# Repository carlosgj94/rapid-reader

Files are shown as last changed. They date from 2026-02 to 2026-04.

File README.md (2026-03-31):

# MOTIF

Embedded Rust firmware for an ESP32-S3 board with a Sharp LS027 memory LCD.

This repository is in a docs-first rebuild state.

Today:

- `src/bin/main.rs` is a minimal bring-up baseline
- `crates/ls027b7dh01` contains the reusable display driver primitives
- `crates/domain`, `crates/app-runtime`, `crates/services`, and `crates/platform-esp32s3` define
  the barebones architecture skeleton
- the baseline already includes the current embassy runtime split, encoder input handling,
  deep-sleep integration, internal flash storage, and boot-hydrated settings
- the new target architecture is documented under `docs/`

The runtime is intentionally thinner than the target system. The technical documentation is now the
source of truth for the rebuild direction.

## Start Here

- [`docs/index.md`](docs/index.md): documentation entrypoint and reading order
- [`docs/architecture/overview.md`](docs/architecture/overview.md): target architecture
- [`docs/flows/article-lifecycle.md`](docs/flows/article-lifecycle.md): end-to-end content flow
- [`docs/modules/provisioning.md`](docs/modules/provisioning.md): BLE-first onboarding model

## Build And Flash

The workspace defaults to `xtensa-esp32s3-none-elf` via `.cargo/config.toml`.
The Cargo runner now passes the Motif partition table and `16mb` flash size explicitly to
`espflash`, and `espflash.toml` keeps the same layout available for direct `espflash` commands.

Flash and monitor:

```bash
cargo run --release
```

Useful local checks:

```bash
cargo fmt --all
cargo check --offline
cargo clippy --offline --workspace --lib
```

## Hardware Docs

- [`docs/board-config.md`](docs/board-config.md): current GPIO wiring used by the stripped firmware
- [`docs/ls027-notes.md`](docs/ls027-notes.md): low-level LS027 protocol notes

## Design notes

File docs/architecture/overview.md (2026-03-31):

# Target Architecture Overview

## Purpose

The next Motif architecture should be optimized for three things at the same time:

- a fast and legible RSVP reading experience
- modularity that supports aggressive review and iterative LLM-assisted implementation
- a clean Rust design that scales without collapsing into one large embedded application module

This document defines the target architecture at the system level. Module-level behavior is
specified in the docs under `docs/modules/`.

## Product Goal

Motif is not a general e-reader and not a web browser. It is a dedicated article-reading device
that uses RSVP presentation to make long-form web reading fast and focused.

The primary content sources are:

- a user's personal saved article queue
- editorial feeds selected or managed by the backend

The device should read smoothly offline after sync. Connectivity improves freshness and state sync,
but should not block the core reading loop.

## Architecture Principles

### One authoritative store, not one giant module

The system should have one authoritative runtime store so every user-visible subsystem can observe
coherent state. That does not mean every module can mutate arbitrary data or that the store becomes
a global dumping ground.

The intended model is:

- state is partitioned into domain slices
- mutations happen through typed commands
- reducers produce state transitions plus effects
- services execute effects and feed typed events back into the store
- selectors produce read models for the app runtime

This preserves the benefits of a central store while keeping Rust ownership explicit and testable.

### Declarative UI with an imperative renderer backend

The app should be expressed as components, view models, and animation descriptors. The LS027
renderer remains an imperative implementation detail that consumes a prepared scene and paints it
efficiently.

Business logic does not live inside rendering code.

### Offline-first reading

Wi-Fi and backend sync are important, but they are support systems around reading. Once content is
synced and formatted, the device should continue to operate without network access.

### Parse once, format once, render many times

The architecture should isolate three different concerns:

- ingesting source material
- normalizing and formatting it into reading structures
- rendering the current UI state

Those steps should not be blended together in one module.

### Small modules with explicit contracts

The implementation should favor more modules than a typical small embedded application. That is an
intentional design choice to keep review boundaries narrow and to make future automated edits
safer.

## Top-Level Module Map

| Module | Purpose | Owns | Does Not Own |
| --- | --- | --- | --- |
| App/UI runtime | Screens, components, navigation, animation descriptors | screen state, component composition, UI-local ephemeral state | transport, storage, parsing |
| Store | Authoritative runtime state and selectors | slice state, mutation pipeline, derived read models | sockets, drivers, file handles |
| Provisioning | First-time setup and reprovisioning | onboarding session lifecycle, BLE claim flow, staged Wi-Fi/backend bundle apply | steady-state Wi-Fi lifecycle, long-term sync scheduling |
| Wi-Fi | Connectivity transport | association state, IP/link status, retry policy | pairing, content sync protocol |
| Backend sync | Device pairing, manifests, article download, progress upload | sync jobs, sync policy, backend protocol | low-level Wi-Fi control, rendering |
| Formatter | Transform canonical article documents into RSVP-ready reading structures | segmentation, normalization, reading units, import adapters | network, UI state |
| Storage | Internal flash and SD coordination | persistence policy, indexes, cached packages | rendering, UI transitions |
| Input | Physical input translation into typed gestures | debouncing, gesture semantics, gesture delivery | navigation logic, rendering |
| Sleep | Inactivity tracking and deep-sleep entry | sleep policy, wake-source selection, wake/sleep signals | sync, formatting, battery telemetry |
| Power | Battery and charging integration when hardware exists | battery telemetry, charging state | article sync, formatting, deep-sleep policy |
| Platform layer | ESP32-S3-specific adapters | hardware bindings, driver setup, OS/task integration | domain rules |
| LS027 driver | Display protocol primitives | framebuffer, protocol framing | app logic, layout, state |

## Planned Workspace Crates

The initial implementation skeleton should be shaped around these workspace crates:

- `motif`
  Root firmware package and binary.
- `domain`
  Shared `no_std` domain/runtime types.
- `app-runtime`
  Shared `no_std` app/runtime surface types.
- `services`
  Shared `no_std` service traits and no-op implementations.
- `platform-esp32s3`
  ESP32-S3 bootstrap and platform facade.
- `ls027b7dh01`
  Display protocol and framebuffer primitives.

## Current Runtime Topology

The current implementation already follows the intended crate split, but only a subset of the
target runtime exists.

Today the concrete runtime shape is:

1. `src/bin/main.rs` enters the thread-mode embassy executor through `esp_rtos`
2. `platform-esp32s3::bootstrap::run_minimal(...)` owns hardware bring-up and the platform loop
3. `app_task` owns `Store` and `AppRuntime`
4. bounded embassy channels and signals move typed events and screens between those sides

The important current coordination paths are:

- `APP_EVENT_CH`
  Platform-to-app event delivery such as input gestures and wake events.
- `PLATFORM_CMD_CH`
  App-to-platform commands. Right now this is used for deep-sleep requests.
- `SCREEN_SIGNAL`
  App-to-platform screen invalidation with the latest `Screen` value.

This is intentionally narrower than the target system, but it already establishes the ownership
pattern the rest of the architecture should follow.

## Core Runtime Objects

The future implementation should revolve around a small set of stable concepts:

- `Store`
  The authoritative runtime state container.
- `Command`
  A typed request to mutate state or schedule work.
- `Event`
  A typed fact emitted after work or external observation.
- `Effect`
  A side-effect request emitted from the store and executed by a service.
- `Selector`
  A derived read model used by the app runtime or another service.
- `ArticleDocument`
  The canonical normalized article representation shared across sync, storage, and formatting.
- `ReadingDocument`
  The formatter output consumed by the RSVP reader.
- `Component`
  A composable app runtime unit with props and optional local ephemeral state.
- `AnimationDescriptor`
  A declarative description of motion tied to a state transition.

The current codebase implements only a small subset of these today:

- `Store`
- `Command`
- `Event`
- `Effect`
- `Screen`
- `InputGesture`
- `SleepModel`
- `StorageHealth`
- skeletal provisioning types

## Recommended Layering

The future code layout should follow this dependency direction:

1. driver layer
2. platform adapters
3. services
4. store and domain/runtime layer
5. app/UI runtime

The direction must not reverse. Rendering, Wi-Fi, SD access, and device power cannot become hidden
dependencies of the app or formatter layer.

## Article-Centric Product Loop

The core product loop is:

1. Pair the device with a backend identity.
2. Discover or refresh personal queue items and editorial feed items.
3. Download normalized article packages and store them locally.
4. Produce formatter outputs and local indexes.
5. Present queue and reader surfaces from store selectors.
6. Persist progress and reading state locally.
7. Sync progress and refreshed content back to the backend when possible.

This loop is described in more detail in [Article Lifecycle](../flows/article-lifecycle.md).

## Ownership Rules

- The store owns user-visible truth.
- Services own external resources and asynchronous work.
- Platform adapters own hardware handles and driver integration.
- Renderer-specific caches and layout caches live outside the store.
- Parsers and source adapters cannot write directly into unrelated slices.
- The app runtime can request work, but cannot bypass the store mutation path.

## Soft Performance Targets

The architecture should optimize for perceived immediacy and bounded work rather than premature
micro-optimizations.

The desired outcomes are:

- input causes visible feedback quickly
- screen transitions complete in a small, predictable number of display commits
- most UI changes avoid unnecessary full-screen re-layout and full-screen repaint
- reading path work is precomputed or cached where possible
- parsing and sync work stay off the hot path for active reading

These are intentionally soft targets for now. Numeric budgets can be added later when the first
real implementation path exists.

## Current Code State

The current repository is intentionally thinner than the target architecture described here, but it
now includes a few real subsystem implementations that are part of the rebuild baseline:

- embassy runtime coordination in `platform-esp32s3::bootstrap`
- rotary encoder gesture decoding
- inactivity-driven deep sleep and wake
- internal flash state and outbox storage
- skeletal provisioning interfaces and BLE-first onboarding documentation

What is still missing is the higher-level product logic:

- queue and reader behavior
- BLE onboarding transport and QR claim flow
- Wi-Fi and backend sync
- formatter pipeline
- broader persistent settings schemas beyond the current inactivity timeout
- SD content management

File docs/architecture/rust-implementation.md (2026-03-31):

# Rust Implementation Guidelines

This document sets the quality bar for the future implementation. It exists to keep the rebuild
from drifting into a monolithic embedded application with vague ownership and brittle async logic.

## Quality Bar

The implementation should look like it was designed, not accumulated.

That means:

- state machines are explicit
- ownership boundaries are narrow
- interfaces are typed and domain-specific
- side effects are isolated
- modules are small enough to review comfortably
- hot paths avoid unnecessary allocation and reparsing

## Recommended Package Boundaries

The initial workspace skeleton should use these crate boundaries:

- `motif`
  Thin firmware entrypoint only.
- `domain`
  Shared runtime/domain concepts.
- `app-runtime`
  Shared app and UI runtime surface types.
- `services`
  Shared service interfaces and no-op service shells.
- `platform-esp32s3`
  ESP32-S3-specific bootstrap and platform adapters.
- `ls027b7dh01`
  Reusable LS027 driver primitives.

The eventual codebase should separate concerns into a few stable layers.

### Domain and runtime layer

Owns:

- commands, events, effects
- store slices
- selectors
- canonical article and reading types
- formatter contracts

This layer should stay platform-agnostic.

### App/UI runtime layer

Owns:

- components
- navigation and screen composition
- animation descriptors
- UI view models

This layer should depend on selectors and formatter outputs, not on hardware drivers.

### Service layer

Owns:

- Wi-Fi orchestration
- backend sync
- storage policy
- input translation
- future power policy

Services may hold async handles and external clients, but they should still communicate with the
rest of the system through typed commands and events.

### Platform layer

Owns:

- ESP32-S3 adapters
- task startup
- driver wiring
- hardware-specific implementations of service contracts

### Driver layer

Owns:

- LS027 protocol and framebuffer primitives

## Design Rules

### Prefer typed state machines over boolean soup

Use enums for lifecycle state. Avoid combinations of booleans that require external knowledge to
interpret.

### Prefer concrete domain types over stringly APIs

Commands, events, selector keys, source kinds, and status markers should be represented with Rust
types, not ad hoc strings and maps.

### Keep effectful code at the edge

Reducers and formatter logic should be pure or nearly pure. Network calls, flash writes, SD I/O,
timers, and hardware interaction belong in services or platform adapters.

### Do not turn traits into an escape hatch

Traits are useful at real boundaries such as parser adapters, storage backends, and platform
services. They should not be used to hide core control flow or to replace normal module structure.

Prefer:

- concrete structs for the dominant implementation path
- enums for closed sets of behavior
- traits only where multiple implementations are genuinely expected

### Keep hot paths allocation-aware

Rendering, reader stepping, and frequently used selector paths should not repeatedly allocate or
reparse data. Precompute and cache durable derived structures where it makes the reading path more
predictable.

### Keep dependency policy strict on embedded paths

This codebase targets a low-level `no_std` device-first runtime.

That means:

- prefer `no_std`-compatible crates on firmware paths
- avoid importing ESP-IDF-oriented convenience layers unless the architecture explicitly changes
- avoid large convenience dependencies that pull in heap-heavy parsing or transport stacks
- justify every new dependency by device-side leverage, not by implementation convenience

For setup-related work in particular:

- provisioning, QR generation, BLE framing, and credential transport must stay compatible with the
  current embedded stack
- library choice should favor bounded memory behavior and small surface area

### Avoid hidden globals

The store is authoritative, but it should be passed and owned explicitly by the runtime. Avoid
mutable global singletons for domain state, service clients, or UI state.

## Concurrency Model

The desired model is cooperative and deterministic:

- the store serializes authoritative mutations
- services perform async work outside the store
- services re-enter the system through typed events
- long-running I/O never blocks the render path

This does not require only one task. It does require one coherent mutation path.

## Current Implemented Runtime Shape

The current firmware already uses that model in a minimal form.

Today:

- `main` starts the embassy-capable `esp_rtos` runtime
- `platform-esp32s3::bootstrap::run_minimal(...)` owns the hardware-facing loop
- `app_task` owns `Store` and `AppRuntime`
- embassy channels and signals are the cross-task boundary

The current async split is:

- platform side
  input sampling, display heartbeat, deep-sleep coordination, boot hardware setup
- app side
  sequential event handling, store mutation, placeholder screen selection

This is the shape future modules should extend rather than bypass.

## Current Async Boundaries

The runtime currently uses embassy timers and coordination primitives rather than a blocking delay
loop:

- `Ticker` for encoder sampling and heartbeat cadence
- `Timer::at(...)` for inactivity sleep deadlines
- bounded channels and signals for app/platform coordination

One important limitation is still intentional in the current baseline:

- LS027 display operations are still synchronous SPI writes inside the platform task

That means the runtime is embassy-shaped and cooperative, but the display path itself is not yet an
async driver.

## Error Strategy

Error handling should stay structured by layer.

- domain/runtime errors describe invalid transitions or unsupported content states
- service errors describe transport, storage, or parser failures
- platform errors describe hardware interaction failures

Avoid flattening all failures into opaque generic error values at the core of the system.

## Testing Strategy

The future test pyramid should look like this:

- unit tests for reducers, selectors, and formatter stages
- scenario tests for article lifecycle flows
- contract tests for parser adapters and storage backends
- platform integration tests for ESP32-specific wiring where feasible

The store mutation model should be easy to exercise in deterministic tests without hardware.

## Observability

The implementation should log and expose meaningful lifecycle facts rather than raw debug noise.

Important categories include:

- pairing and sync phases
- content ingestion and formatter failures
- storage degradation
- UI navigation and reader session transitions
- wake, sleep, and power events when that subsystem exists

## Reviewability Rules

To keep the codebase maintainable under human and automated editing:

- prefer many small modules over a few huge files
- keep public interfaces narrow
- make ownership readable from the type signatures
- avoid mixing domain logic, formatting logic, and platform code in one file
- keep each module responsible for one layer of abstraction

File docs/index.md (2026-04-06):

# Motif Technical Documentation

This documentation set defines the target architecture for the next implementation phase and the
current implementation baseline where concrete subsystems already exist.

The codebase is still intentionally thin, but it is no longer only a bare bring-up binary. The
current firmware now includes:

- an embassy-shaped runtime split between platform ownership and app/store processing
- a working rotary-encoder gesture pipeline
- deep sleep and wake handling tied to inactivity and the encoder switch
- a durable internal-flash storage engine for compact records and an outbox queue
- a boot-hydrated live store with real `device`, `settings`, `sleep`, `input`, and `storage`
  state
- a selector-driven app runtime with prepared screens and display-friendly transitions
- a mock-script-backed RSVP reader with timed playback, pause, paragraph navigation, and chat mode
- a theme-aware renderer with persisted appearance and reader-preference settings
- real station-mode Wi-Fi with reconnect, DHCP/IP state, and backend-path probing
- real backend refresh, paginated Saved sync, and streaming package acquisition
- SD-backed package staging/commit/open flows with PSRAM-backed reader working sets
- uncached article opens that can queue across startup/network wobble and resume automatically
- skeletal provisioning interfaces for BLE-first onboarding

The docs below call out when a section describes the current implementation versus the longer-term
target shape.

## Product Definition

Motif is a dedicated RSVP reading device for internet articles on ESP32-S3 hardware with a Sharp
LS027 memory LCD.

The target product loop is:

1. Sync a user's personal saved articles and editorial feeds from the backend.
2. Cache normalized article packages locally.
3. Format those packages into RSVP-ready reading structures on device.
4. Render a fast, motion-capable reader UI with offline-first behavior.
5. Persist reading progress locally and sync it back when the network is available.

## Reading Order

1. [Architecture Overview](architecture/overview.md)
2. [Article Lifecycle](flows/article-lifecycle.md)
3. [Rust Implementation Guidelines](architecture/rust-implementation.md)
4. [Store](modules/store.md)
5. [Settings](modules/settings.md)
6. [Provisioning](modules/provisioning.md)
7. [App And UI Runtime](modules/app-ui.md)
8. [Wi-Fi](modules/wifi.md)
9. [Backend Sync](modules/backend-sync.md)
10. [Formatter And Content Pipeline](modules/formatter.md)
11. [Storage](modules/storage.md)
12. [Input](modules/input.md)
13. [Sleep](modules/sleep.md)
14. [Power Placeholder](modules/power.md)
15. [Session Progress: RSVP, Theme, And Persistence](progress/2026-04-01-rsvp-session.md)
16. [Session Progress: Network Reliability And Throughput](progress/2026-04-05-network-reliability-and-throughput.md)
17. [Session Plan: Network And Storage Stability](progress/2026-04-06-network-and-storage-action-plan.md)
18. [Network And Storage Tickets](progress/2026-04-06-network-and-storage-tickets.md)

## System At A Glance

- The app runtime is declarative and component-based rather than screen-by-screen imperative code.
- The store is the single authoritative runtime state container, but domain ownership stays split
  by slice and module.
- Provisioning owns first-time setup and reprovisioning.
- Wi-Fi only manages connectivity.
- Backend sync manages pairing, manifests, article packages, and progress exchange.
- Formatter owns the transformation from canonical article data to RSVP-ready reading units.
- Internal storage and SD storage have distinct responsibilities.
- Hardware-specific implementation stays at the platform edge.

## Current Implemented Baseline

Today the codebase concretely implements:

- the workspace split across `domain`, `app-runtime`, `services`, `platform-esp32s3`, and
  `ls027b7dh01`
- an embassy-based runtime handoff between the platform loop and an `app_task`
- typed input gestures for the rotary encoder
- inactivity-based deep sleep with button wake
- internal flash partitions `motif_state` and `motif_outbox`
- persisted settings hydration into the live store and platform sleep service
- persistence of user settings snapshots through the storage module and platform effect handling
- selector-driven prepared screens and renderer transition planning
- a formatter-backed mock RSVP reading flow with timed reader ticks and paragraph anchors
- real Wi-Fi station connectivity with backend-path readiness probing
- backend refresh-token exchange, paginated Saved sync, and streaming package fetch
- SD-backed content staging, commit, cached package open, and reader-window loading
- PSRAM-backed request buffers plus selected reader/storage working sets
- measured throughput and retry improvements across the uncached-open path
- skeletal provisioning interfaces and BLE-first onboarding documentation

The codebase still does not yet implement the full provisioning and
progress-upload systems described elsewhere in these docs, and the networking
stack still needs more reliability hardening around DNS, TLS, and Wi-Fi churn.

## Current Hardware References

- [Board Integration Contract](board-config.md)
- [LS027 Notes](ls027-notes.md)

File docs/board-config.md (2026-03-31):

# Board Integration Contract

This note documents the current hardware contract used by the stripped firmware baseline and by the
target architecture docs.

## Current Wiring

### Display

- `GPIO13` -> `CLK` / display SPI SCK
- `GPIO14` -> `DI` / display SPI MOSI
- `GPIO15` -> `CS` / `SCS`
- `GPIO2` -> `DISP`
- `GPIO9` -> `EMD` / `EXTCOMIN`

Current display assumptions:

- LS027 uses SPI mode 1 in firmware.
- The stripped firmware initializes the panel, clears it once, and then refreshes a minimal
  heartbeat frame.
- On deep sleep entry, firmware clears the panel, drives `DISP` and `EMD` low, and holds those
  RTC pins low during sleep.

### SD Card

- `GPIO8` -> `CS`
- `GPIO4` -> `SCK`
- `GPIO40` -> `MOSI`
- `GPIO41` -> `MISO`

Current SD assumptions:

- The target architecture uses SD for article packages, assets, imports, and larger caches.
- The stripped firmware baseline does not currently initialize the SD path.

### Rotary Encoder

- `GPIO10` -> `CLK`
- `GPIO11` -> `DT`
- `GPIO12` -> `SW`

Current input assumptions:

- The target architecture treats the encoder as the primary navigation input.
- Firmware currently initializes the encoder path for rotation, click, and long-press detection.
- Rotary movement is polled on a short cadence.
- The encoder switch uses GPIO edge interrupts while awake.
- The current encoder software contract is one gesture per detent, plus `Click` and `LongPress`.
- The current long-press threshold is `600 ms`.

### Battery / Power Sensing

- Battery telemetry is not currently wired into the PCB path for software integration.
- The future power module should be treated as an architectural placeholder until that hardware
  path exists.

### Deep Sleep Wake

- `GPIO12` is the provisional deep-sleep wake input in software.
- This uses the encoder switch path until a dedicated wake button exists.
- Firmware consumes the wake press until release so a wake does not also trigger a click event.

## Board-Level Responsibilities

The current stripped firmware owns:

- minimal ESP32-S3 bring-up
- LS027 init and framebuffer flush
- embassy runtime wiring between platform and app/store tasks
- rotary encoder gesture decoding and queueing
- inactivity-based deep sleep and wake
- internal flash storage mounting and health logging
- GPIO contract logging for display, SD, and encoder pins

Hardware design files under the KiCad project directory are left untouched by this reset.

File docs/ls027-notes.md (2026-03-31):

# LS027B7DH01 Notes

Source: `LS027B7DH01_Rev_Jun_2010.pdf`.

## Fixed panel facts
- Resolution: 400 x 240 pixels (1bpp)
- Line payload: 400 bits = 50 bytes
- Lines: 1..=240

## Key timing used for initial bring-up
- SPI clock (`fSCLK`): start at 1 MHz
- Frame update cadence (`fSCS`): start at 1 Hz equivalent test cadence
- EXTCOMIN: start at 1 Hz square wave (toggle every 500 ms)

## Interface signals
- `SCLK`: SPI clock
- `SI`: SPI data input (MOSI)
- `SCS`: chip select, active-high framing signal
- `DISP`: display enable pin
- `EXTCOMIN`: external common inversion input

## Protocol framing assumptions
- Mode bits are sent in order `M0 M1 M2`, then dummy bits.
- For data update of one line:
  - mode select (3 bits) + dummy (5 bits)
  - gate line address (`AG0..AG7`, 8 bits)
  - line data (`D1..D400`, 400 bits)
  - transfer dummy (16 bits)
- For all-clear:
  - mode select with `M0=0, M2=1`
  - at least 13 dummy bits afterward

## Address mapping assumption
- Gate address is little-endian by line number bits: `AG0` is line bit 0.
- Wire byte for address in MSB-first SPI is `reverse_bits(line_number as u8)`.
  - L1 -> `0x80`
  - L2 -> `0x40`
  - L3 -> `0xC0`
  - L240 (`0xF0`) -> `0x0F`

## Pixel bit order assumption
- First pixel in a line (`D1`) maps to bit 7 of byte 0.
- Pixel index in line maps to `(byte = x / 8, bit = 7 - (x % 8))`.

These assumptions are intentionally explicit so bring-up can validate/fix one dimension at a time if behavior differs on hardware.

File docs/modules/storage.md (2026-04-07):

# Storage

## Purpose

The storage layer is the persistence boundary for Motif.

It owns two different media classes:

- internal flash for small, durable device state
- SD storage for larger article packages, assets, and future imports

This module should never degenerate into scattered raw flash writes from app or platform code.

## Current Internal Flash Design

The current implementation is a durable internal-flash engine in
`crates/platform-esp32s3/src/storage.rs`.

It is intentionally narrow:

- singleton records for compact state
- a durable append-only outbox queue
- raw NOR flash access through `esp-storage::FlashStorage`
- no filesystem
- no encryption in this first pass

The target hardware assumption is the ESP32-S3 N16R8-class device:

- `16 MB` internal flash
- `8 MB` PSRAM

PSRAM is for working memory and caches. It is not authoritative persistence.

## Internal Flash Partitions

The firmware now expects a custom partition table in `partitions/motif.csv`.

Two Motif-owned partitions are reserved:

| Partition | Size | Purpose |
| --- | --- | --- |
| `motif_state` | `256 KiB` | latest-value singleton records and compact metadata |
| `motif_outbox` | `256 KiB` | durable queued items awaiting future sync ack |

The current flashing config in `espflash.toml` assumes the 16 MB module and uses that partition
table by default.

## Record Model

Internal state is append-only and copy-on-write.

Every state record write appends a new committed entry rather than rewriting older data in place.
Delete is represented by a tombstone entry.

Each committed slot carries:

- record magic
- format version
- logical record key
- schema version
- monotonic sequence
- payload length
- CRC32
- commit marker written last

A record is valid only if:

- the header parses
- the payload length is sane
- the CRC matches
- the commit marker is present

That rule is what protects against battery loss during a write.

## Outbox Model

The outbox partition is also append-only.

It stores:

- `enqueue` records for new items
- `ack` records that retire a previously queued sequence number

Boot recovery reconstructs the live queue as:

- all committed enqueue records
- minus any later committed ack record for the same sequence

This avoids in-place queue mutation and keeps recovery logic deterministic.

## Bank Layout and Recovery

Each partition is split into two erase-aligned banks.

The active bank accepts append-only writes until it runs out of room. At that point the engine:

1. scans the live committed data in the active bank
2. erases the inactive bank
3. copies only live data into the inactive bank
4. commits the inactive bank header
5. flips the active-bank pointer

Only after a valid destination bank exists is the previous bank considered disposable.

This means power loss during compaction should not destroy the last committed state.

On boot, mount and recovery:

- scan both banks
- select the newest committed valid bank
- ignore torn or corrupt records
- initialize a fresh bank if neither side is valid

## Service Boundary

The shared contract lives in `crates/services/src/storage.rs`.

The important abstractions are:

- `RecordCodec`
- `QueueCodec`
- `StorageService`
- `StorageHealth`
- `RecordKey`
- `QueueSeq`

The API is typed on purpose. Callers work with record codecs and queue codecs, not raw offsets.

Reserved record families at the architecture level are:

- device settings snapshots
- active Wi-Fi credential
- Wi-Fi credentials or remembered network configuration
- backend credential or device token
- backend token or device credential material
- device identity and pairing metadata
- provisioning metadata for recovery and reprovisioning hygiene
- storage migration metadata

The storage layer does not lock those schemas yet. It only provides the durable pattern.

## SD Responsibilities

SD remains the place for heavier payloads:

- normalized article bodies
- assets
- future EPUB and TXT imports
- staging areas and derived caches that do not belong in internal flash

Internal flash must stay small, durable, and cheap to recover.

## Current SD Package Pipeline

The SD path is now much more concrete than the original architecture notes.

Current implemented behavior includes:

- bounded streaming package writes through the storage command path
- open-handle staging so the active file is not reopened for every chunk
- asynchronous queued package writes instead of an ACK-blocking round trip per
  chunk
- direct writes to a free final package slot where safe, with `copied_bytes=0`
  on commit
- immediate open-after-commit for uncached article prepares
- runtime SD SPI that initializes conservatively at `400 kHz` and switches to
  a product-default `8 MHz` after mount
- boot/storage telemetry that records the SD init clock, runtime clock, and the
  source of that runtime choice
- a controlled build-time override path (`MOTIF_SD_SPI_RUN_HZ`) for deliberate
  higher-clock experiments without changing the product default

Current package/stage buffers are intentionally much larger than the original
baseline:

- package download chunk length: `131072` bytes by default
- stage/storage handoff chunk length: fixed at `65536` bytes so storage starts
  draining before the receive buffer fills completely
- stage flush interval: `131072` bytes

Those values now come from one shared fixed transfer-tuning policy so backend
and storage stay coordinated without forcing the storage path to buffer a full
`128 KiB` article burst before the first SD write. The repo still exposes a
deliberate build-time override (`MOTIF_PACKAGE_TRANSFER_CHUNK_LEN`) for
controlled A/B tests within the `8 KiB ..= 128 KiB` range without forking the
code.

That work removed SD throughput as the primary bottleneck on healthy runs.

## Guarantees and Non-Goals

Current guarantees:

- no in-place overwrite of the live singleton value
- torn writes are ignored
- corrupt CRC entries are ignored
- queue ack is durable
- storage health can be reported at boot

Current non-goals:

- encryption at rest
- wear-leveling beyond the simple dual-bank copy-on-write model
- arbitrary large-value storage
- direct flash access from app code

## Implementation Status

What exists now:

- typed storage contracts in `domain` and `services`
- a mounted flash-backed internal storage engine in `platform-esp32s3`
- runtime partition discovery by label
- a real persisted-settings record used during bootstrap hydration
- an expanded persisted-settings snapshot carrying timeout, RSVP speed, appearance, and topic
  preferences
- app-level settings persistence through typed store effects executed by the platform storage path
- startup configuration now logs the effective hydrated settings after that record is applied
- recovery, compaction, and queue semantics
- storage health reporting during boot
- persisted backend credential records used by refresh/session startup
- a real SD-backed content/package pipeline with staging, commit, abort, and
  cached package open flows
- PSRAM-backed reader/storage working sets for initial package open and reader
  materialization

What does not exist yet:

- Wi-Fi credential records
- broader app-level persistence beyond settings snapshots and current content
  metadata
- persisted local reading-progress records and remote progress upload

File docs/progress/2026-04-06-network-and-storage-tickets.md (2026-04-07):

# Network And Storage Tickets

These tickets are the durable execution backlog after the April 5 throughput
and memory work.

## Ticket 11: DNS And Endpoint Recovery Hardening

### Why

Current runs still show repeated on-device DNS failures during startup refresh
and uncached article opens. Throughput is good enough now that DNS instability
is a primary reliability problem.

### Scope

- add a last-good backend IPv4 cache in RAM
- key the cache to the current network session so disconnect or DHCP change
  invalidates it
- after DNS failure, allow refresh/package requests to retry against the cached
  endpoint while preserving hostname semantics for HTTP Host and TLS SNI
- log cache hit, miss, age, invalidation reason, and fallback success

### Current Progress

- Code landed: the Wi-Fi layer now holds a session-scoped last-good backend
  endpoint cache, probe fallback can use it within the same network session,
  and backend session open / startup refresh now try that cached endpoint
  before declaring DNS dead.
- On-device validation passed: request-side fallback is now visible in device
  logs, including a successful `backend request dns fallback succeeded`
  recovery path during the April 7 handoff experiments.

### Non-goals

- no Wi-Fi driver tuning here
- no timeout redesign here
- no backend API changes

### Done When

- transient DNS failure no longer kills uncached opens so easily
- fallback behavior is visible in logs
- fallback success can be counted in later soak reports

## Ticket 12: Timeout And Request-Class Policy

### Why

The current firmware still shares too much timeout behavior across startup
refresh, buffered metadata fetches, and streaming package requests.

### Scope

- define explicit timeout budgets for:
  - startup refresh
  - buffered metadata pages
  - streaming package fetch
- make the policy visible in code and telemetry rather than hiding it in shared
  constants
- revisit handshake, body-read, and flush budgets using the April 5 and April 6
  traces as the baseline evidence
- add request-class tags to timeout and timing logs

### Current Progress

- Code landed: backend requests now carry an explicit request class
  (`auth_refresh`, `buffered_metadata`, `streaming_package`), timeout budgets
  are selected per class instead of through shared global constants, and the
  class is now emitted in request timing/phase/headers/progress/complete
  telemetry.
- On-device validation passed in `/tmp/motif-ticket12b.log`: startup reached
  `Ready`, no inactivity sleep fired during dashboard sync, and the run showed
  zero timeout-style transport failures across refresh, metadata, and package
  requests.
- Residual observation: one reused `streaming_package` session delivered a
  `57,123` byte package in about `20s`, while fresh/resumed streaming sessions
  for larger packages completed materially faster. That looks like a follow-up
  on package-session reuse policy, not a reason to keep Ticket 12 open.

### Non-goals

- no DNS fallback here
- no Wi-Fi driver default cleanup here
- no throughput tuning unless a timeout decision requires it

### Done When

- timeout behavior is explainable per request class
- startup and package paths stop sharing obviously mismatched budgets
- false-positive transport failures are measurably reduced

## Ticket 13: Wi-Fi Driver Config And Observability

### Why

The current Wi-Fi path still inherits important behavior from `esp-radio`
defaults. That hides useful facts such as the effective country code,
power-save mode, and driver-level disconnect context.

### Scope

- replace implicit `Default::default()` dependence with explicit Motif-owned
  Wi-Fi config where practical
- explicitly set and log the effective power-save mode
- explicitly set and log the effective country code instead of inheriting the
  vendored `CN` default silently
- log disconnect reason codes and other high-signal radio transitions
- log the effective Wi-Fi driver config at boot so field traces are
  self-describing

### Current Progress

- Code landed: Motif now sets Wi-Fi power-save mode explicitly, hardcodes the
  product-default country code to `ES`, logs the effective driver config at
  boot, and logs `StaConnected` / `StaDisconnected` events with disconnect
  reason and RSSI.
- Still pending: device validation of the new logs on hardware.

### Non-goals

- no speculative power-save enablement here
- no DNS fallback here
- no timeout-policy redesign here

### Done When

- logs show the effective Wi-Fi config without reading source code
- power-save mode and country code are explicit Motif decisions
- disconnects carry actionable reason data instead of only generic
  "disconnected"

## Ticket 14: Network Soak And SLI Reporting

### Why

The project now needs service-level reliability evidence, not just individual
trace reading.

### Scope

- extend reporting to summarize:
  - startup retry count
  - Wi-Fi disconnect count
  - DNS failure count
  - TLS handshake timeout count
  - flush/body-read timeout count
  - package success ratio
  - median and p95 request time by request class
  - SD mount/commit/open failure count
- define a repeatable soak-run protocol for manual sessions
- make the report output easy to compare across tickets

### Current Progress

- Code landed: `scripts/memtrace_report.py` now parses both `MEMTRACE` rows and
  high-signal plain log lines, emits `sli.csv`, `request-class-summary.csv`,
  and `log-events.csv`, and adds reliability / request-class sections to the
  Markdown summary.
- The report now summarizes startup retries, Wi-Fi disconnects, DNS fallback
  attempts and hard failures, TLS handshake timeouts, flush/body-read
  timeouts, package success ratio, per-class attempt/success counts, and
  median / p95 successful request latency by request class.
- Manual soak protocol captured in
  [2026-04-06-network-soak-protocol.md](2026-04-06-network-soak-protocol.md)
  so repeated runs use the same capture and report commands.

### Non-goals

- no firmware tuning here unless reporting requires a new event field
- no backend API changes

### Done When

- repeated runs produce comparable reliability summaries
- tickets can be judged by success rate, not only by feel
- the repo has a lightweight soak protocol the team can keep using

## Ticket 15: SD Runtime Stability And Clock Validation

### Why

The SD runtime clock jump to `8 MHz` delivered a real performance win, but it
still needs an explicit stability and integrity pass before being treated as a
finished hardware setting, and any move above `8 MHz` must be evidence-driven.

### Scope

- validate mount, stage, abort, commit, reopen, and post-sleep behavior at the
  current `8 MHz` runtime clock
- add or tighten SD-specific observability if the current logs are not enough
  to diagnose mount/reopen/CRC issues
- only after a clean repeated run set, do one controlled A/B test at a higher
  runtime clock such as `12 MHz`
- keep the higher clock only if it is stable and yields a real end-to-end win

### Current Progress

- Code landed: the SD runtime clock is now an explicit product-default policy
  instead of an unlabeled raw constant, storage static-inventory and boot mount
  telemetry now emit the init/runtime clock and source, and a controlled
  build-time override path (`MOTIF_SD_SPI_RUN_HZ`) exists for later `12 MHz`
  A/B runs.
- Still pending: repeated on-device stability runs at the retained `8 MHz`
  setting, then one evidence-driven higher-clock experiment only if `8 MHz`
  stays clean.

### Non-goals

- no package protocol redesign here
- no chunk-size changes here
- no storage-format changes here

### Done When

- repeated stage/commit/open cycles are stable at the retained clock
- any higher-clock experiment is justified by measured gain and zero integrity
  regressions
- SD runtime configuration is documented as a deliberate choice rather than a
  lucky value

## Follow-up Experiment: Package Transfer Chunk Tuning

### Why

Longer soak runs are now mostly reliable, but uncached article opens are still
slower than they should be. The current package path is stable enough that it
is reasonable to try a more aggressive transfer profile.

### Scope

- widen the chunk size materially beyond the original `8 KiB` baseline
- keep stage flush cadence derived from the storage handoff chunk so larger
  receive buffers do not force the storage side into all-or-nothing bursts
- make the effective transfer profile explicit in boot and static-inventory
  logs
- keep an easy build-time override for A/B runs at even larger chunk sizes
- keep storage handoff smaller than the receive-side socket buffer so package
  streaming and SD writes can overlap again

### Current Progress

- Code landed: backend package streaming and storage staging now read their
  receive/handoff sizes from one shared transfer-tuning policy instead of
  separate raw constants.
- The current product-default transfer profile is `131072` byte receive chunks,
  a fixed `65536` byte storage handoff chunk, and a derived `131072` byte
  stage flush interval. The intermediate adaptive handoff experiment was
  removed after A/B runs because it added complexity without a durable win over
  the simpler fixed profile.
- A controlled build-time override path
  (`MOTIF_PACKAGE_TRANSFER_CHUNK_LEN`) exists for deliberate higher-chunk A/B
  runs without touching the code again, and the current guardrail allows
  experiments anywhere in the `8 KiB ..= 131072` byte receive range.

### Non-goals

- no Wi-Fi retry redesign here
- no TLS/session reuse redesign here
- no storage format changes here

### Done When

- repeated article-download runs show a real end-to-end latency win
- higher chunks do not introduce alloc or corruption regressions
- the effective package transfer profile is obvious from the logs

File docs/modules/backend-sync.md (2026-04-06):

# Backend Sync

## Purpose

Backend sync is the device's bridge to remote product state.

It owns:

- refresh-token based session renewal
- saved/recommendation collection refresh
- normalized article package acquisition
- transport retry policy above the Wi-Fi layer
- publication of sync/content availability into the store

It depends on Wi-Fi/backend-path readiness, but it is not the Wi-Fi module.

## Current Implemented State

Backend sync is no longer a skeleton.

The current firmware in `crates/platform-esp32s3/src/backend.rs` now implements:

- refresh-session exchange against `/device/v1/auth/session/refresh`
- paginated Saved collection refresh with bounded page size
- streaming package fetch for uncached articles
- shared package-transfer tuning for backend chunk size and storage staging
- reusable access sessions plus serialized TLS session resumption
- package retry and recovery logic that coordinates with backend-path readiness
- direct handoff into storage staging/commit/open flows
- typed status publication back into the store

On a blank card, Saved can now repopulate and uncached article opens can
complete without relying on oversized buffered responses.

## Current Runtime Shape

At a high level the current flow is:

1. wait for backend-path readiness from the Wi-Fi layer
2. refresh the access session
3. fetch Saved metadata in bounded pages
4. publish collection updates into the store
5. on uncached open, stream the package through storage
6. commit and open the package locally

When the path is healthy, current package fetch timings are already
substantially improved from the original baseline. Recent successful runs show:

- `54067` byte package in about `4476 ms`
- `140395` byte package in about `10002 ms`
- `219227` byte package in about `13702 ms`

That means backend sync is no longer dominated by the old SD/package pipeline.

## Current Remaining Problems

The main remaining failures are network-side, not storage-side:

- occasional startup Wi-Fi churn / disconnects
- occasional stream interruption after a disconnect
- package/session reuse paths that can still be slow without fully failing
- incomplete on-device validation of backend request-side DNS fallback

When these occur, backend sync can still fail an uncached article open even
though the happy path is now fast.

## Pairing And Credential Model

The current implementation still assumes a stored refresh token / device-side
credential rather than a full login UI. Provisioning remains the source of that
credential; backend sync owns using and refreshing it.

## Storage Boundary

Backend sync still must not write raw files directly. It asks storage to:

- begin package staging
- append package chunks
- commit or abort staged content
- open committed reader content

That keeps persistence policy and recovery logic inside the storage boundary.

## Still Missing

The architecture still has important unfinished areas:

- progress upload and remote reconciliation
- stronger recovery after mid-stream disconnect/body-read failure
- more evidence on higher-throughput package transfer tuning
- compile-time TLS feature pruning
- automated long-run soak infrastructure beyond the current manual reports

Those are now the next frontier for turning the current implementation from a
working prototype into a more production-grade network client.

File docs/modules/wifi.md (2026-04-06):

# Wi-Fi

## Purpose

The Wi-Fi module owns radio-level connectivity and the local evidence for
"can the device actually reach the backend right now?"

It answers:

- is the station started
- is the device associated
- does the device have an IP address
- has backend-path reachability been proven recently enough to trust requests
- are we offline, reconnecting, or degraded

It does not own auth tokens, manifest policy, article semantics, or reader
behavior.

## Responsibilities

- station start and reconnect lifecycle
- association and disconnect handling
- IP availability reporting
- backend-path probe execution and readiness tracking
- invalidating readiness on link, DNS, connect, TLS, or request-I/O failure
- publishing typed network status upward to the store/backend sync layer

## Non-Responsibilities

- onboarding and provisioning ownership
- backend refresh-token exchange
- collection pagination and package downloads
- reader open policy
- storage writes

Those belong to provisioning, backend sync, and storage.

## Current Implemented State

Wi-Fi is no longer a stub.

The current firmware now has a real station-mode connection task in
`crates/platform-esp32s3/src/internet.rs` with:

- station config and start
- reconnect after disconnect
- DHCP/IP-backed online state
- a probe task that confirms backend-path reachability with real DNS+connect
- a shared backend-path readiness bit that request code can wait on
- invalidation of that readiness when Wi-Fi, DNS, connect, TLS, or request I/O
  fails

This means the rest of the firmware no longer treats "associated with an IP"
as equivalent to "safe to spend backend retries."

## Current Configuration Reality

Important current facts:

- Motif now constructs Wi-Fi with an explicit driver config rather than passing
  `Default::default()` through untouched
- modem power-save mode is explicitly set to `None`
- the country code is explicitly set to `ES`
- client association still starts from `ClientConfig::default()`

So power save is probably not the reason for the present instability, but there
is still more driver-level policy and observability work to do before this
looks like a production-quality networking stack.

## Known Gaps

Current reliability work is now concentrated here:

- repeated on-device DNS failures
- occasional Wi-Fi disconnect/reassociate churn
- driver-level policy is still incomplete beyond power-save and country code
- last-good-endpoint fallback still needs field validation under real DNS wobble

These are now higher priority than raw package-throughput tuning.

## Interaction With Backend Sync

Backend sync is allowed to depend on Wi-Fi's backend-path readiness signal, but
Wi-Fi still does not own higher-level retry policy.

The split is:

- Wi-Fi says whether the transport path is plausibly usable
- backend sync decides which request class to run, how many attempts to spend,
  and what to do when content fetches fail

That keeps radio/transport concerns separate from product semantics.

## Persistence Boundary

Wi-Fi credentials should still live in internal storage rather than inside
transient radio state. The firmware currently assumes one active network, and
future provisioning should continue to stage credentials before replacing the
active record.

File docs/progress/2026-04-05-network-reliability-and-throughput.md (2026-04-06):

# Session Progress: Network Reliability And Throughput

This note summarizes the concrete networking, PSRAM, storage, and throughput
work completed in the April 5, 2026 session.

## Implemented

- Enabled PSRAM in octal mode and added it to the allocator.
- Added dual-heap telemetry so internal and external pressure are visible in
  logs and reports.
- Established an explicit memory-placement policy and moved safe request
  buffers plus selected reader/storage working sets into PSRAM.
- Replaced oversized Saved collection fetches with bounded pagination, fixing
  the earlier `ResponseTooLarge` failure mode on blank cards.
- Reworked package download/staging to remove the most obvious throughput
  bottlenecks:
  - larger package and stage chunks
  - bounded flush policy
  - async queued storage writes
  - open-handle staging
  - direct writes to free final package slots
  - immediate open-after-commit for uncached articles
- Raised the runtime SD SPI clock to `8 MHz` after mount.
- Added runtime TLS session resumption and backend-path readiness / reprobe
  gating.
- Moved large long-lived async task state out of embassy task storage and grew
  the stable internal heap budget to `160 KiB`.
- Added queueing for uncached article opens when the backend is temporarily
  unavailable, plus sleep suppression while a fetch is active.

## Measured Impact

Healthy package and open timings are dramatically better than the early April 5
baseline.

Representative request improvements:

- early baseline:
  - `88199` byte package in `25440 ms`
  - `219227` byte package in `25440 ms`
  - `219227` byte commit in `32512 ms`
- later healthy run:
  - `54067` byte package in `4476 ms`
  - `140395` byte package in `10002 ms`
  - `219227` byte package in `13702 ms`
  - `219227` byte commit in `15132 ms`

This means package throughput and SD staging are no longer the primary limiter
when the network path is healthy.

## Current Product-Level Result

The firmware now has:

- real backend-driven Saved sync
- real uncached article download and local open
- much faster package and commit paths
- materially better internal-memory headroom during reader open
- retry/recovery behavior that can survive some DNS and transport wobble

Recent healthy runs can open uncached articles in the rough range of:

- `54 KB` article: about `4.5 s` package request
- `140 KB` article: about `10.0 s` package request
- `219 KB` article: about `13.7 s` package request

## Still Failing

The remaining reliability issues are now concentrated in the network stack:

- Wi-Fi disconnect/reassociate churn
- on-device DNS failure
- occasional TLS handshake timeout
- occasional request flush / stream-read instability

These failures now dominate user-visible problems more than raw SD or package
throughput does.

## What To Do Next

The next work should prioritize reliability over more throughput tuning:

1. DNS and endpoint-recovery hardening
2. request-class specific timeout policy
3. explicit Wi-Fi driver configuration and observability
4. soak metrics and service-level reliability reporting

That is the work needed to move the current networking path from a capable
prototype to a more production-grade embedded client.

The follow-up execution backlog is documented in
[Session Plan: Network And Storage Stability](2026-04-06-network-and-storage-action-plan.md)
and
[Network And Storage Tickets](2026-04-06-network-and-storage-tickets.md).

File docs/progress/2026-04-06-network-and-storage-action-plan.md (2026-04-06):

# Session Plan: Network And Storage Stability

This is the execution plan for the April 6, 2026 session.

## Goal

Move the current firmware from "fast on healthy runs" to "predictably reliable
under normal Wi-Fi and SD-card churn" without giving back the throughput gains
already landed on April 5.

## Current Baseline To Preserve

- PSRAM enabled in octal mode
- internal heap held at `160 KiB`
- backend TCP buffers at `16 KiB` RX / `4 KiB` TX
- package and stage chunk sizes at `8 KiB`
- SD SPI at `400 kHz` init and `8 MHz` runtime
- package fetch retry budget at `3` attempts

These settings are the current reference point. Do not change multiple knobs at
once unless a ticket explicitly says to.

## What Is Already Good

- Saved sync is no longer blocked by oversized buffered responses.
- Healthy uncached package fetches are much faster than the original baseline.
- Direct package-slot commit and open-after-commit are working.
- PSRAM is now used for request buffers and selected reader/storage working
  sets.

## What Is Still Failing

- intermittent Wi-Fi disconnect / reassociation churn
- on-device DNS failure
- occasional TLS handshake timeout
- occasional request flush or stream-read instability
- SD stability has improved, but the current `8 MHz` runtime clock still needs
  a deliberate stability and integrity pass before pushing it higher

## Execution Order For Today

1. [Ticket 13: Wi-Fi Driver Config And Observability](2026-04-06-network-and-storage-tickets.md#ticket-13-wi-fi-driver-config-and-observability)
2. [Ticket 11: DNS And Endpoint Recovery Hardening](2026-04-06-network-and-storage-tickets.md#ticket-11-dns-and-endpoint-recovery-hardening)
3. [Ticket 12: Timeout And Request-Class Policy](2026-04-06-network-and-storage-tickets.md#ticket-12-timeout-and-request-class-policy)
4. [Ticket 15: SD Runtime Stability And Clock Validation](2026-04-06-network-and-storage-tickets.md#ticket-15-sd-runtime-stability-and-clock-validation)
5. [Ticket 14: Network Soak And SLI Reporting](2026-04-06-network-and-storage-tickets.md#ticket-14-network-soak-and-sli-reporting)

## End-Of-Day Success Criteria

- no hidden Wi-Fi driver defaults remain for power-save mode or country code
- DNS failure no longer kills article opens as easily
- timeout behavior is explicit per request class
- SD stage/commit/open flows are validated repeatedly at the retained runtime
  clock, and any higher-clock experiment is justified by data
- reliability is summarized with repeatable metrics instead of one-off log
  anecdotes

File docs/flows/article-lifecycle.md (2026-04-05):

# Article Lifecycle

This document traces one article through the current Motif firmware and calls
out where the implementation already matches the target architecture versus
where it is still incomplete.

## Overview

The product still has two first-class upstream source classes:

- personal saved articles
- editorial feed articles

The current firmware is much further along on the Saved path than on the full
editorial-feed path, but the local package and reader pipeline is shared.

## Phase 1: Discovery

Today discovery happens through backend sync after refresh-session success.

Current implemented behavior:

- backend sync waits for backend-path readiness from the Wi-Fi module
- it refreshes the access session
- it fetches Saved content metadata in bounded pages
- it publishes collection updates into the store

The important correctness change already landed: discovery is no longer blocked
by one oversized buffered Saved response.

## Phase 2: Package Acquisition

For articles that are missing locally, backend sync requests a normalized
package from the backend.

Current implemented behavior:

- uncached opens trigger a streaming package request
- the store can queue that open if the backend path is not yet usable
- package bytes stream through the storage module instead of going directly to
  the reader
- retries coordinate with backend-path recovery rather than burning all attempts
  blindly on a marginal link

This path is now materially faster than the original baseline, but it still
fails sometimes when DNS, Wi-Fi, or TLS churn.

## Phase 3: Local Materialization

The storage layer now performs real staging and commit work on SD.

Current implemented behavior:

- package chunks are staged through the storage queue
- the active stage file stays open during the download
- free-slot downloads can write directly to the final package slot
- successful uncached opens can commit and open immediately
- failed prepares abort the stage instead of leaving partial packages live

This means package presence and reader open are now much closer together in the
uncached-open path than they were originally.

## Phase 4: Reader Materialization

Once the package is committed:

- storage opens the cached reader package
- paragraph metadata and the initial reader window are materialized
- the store opens the reader session and transitions the UI to Reader

Current reader/storage working sets now prefer PSRAM where safe, which reduces
internal-memory pressure during open and paging.

## Phase 5: Queue Presentation

The Saved view is derived from store-backed collection state.

Current implemented behavior:

- metadata can appear before the package is local
- package state is surfaced per item
- uncached taps while the backend is not usable are now queued instead of being
  dropped
- a queued item stays visibly `Fetching` across collection refreshes

This is important because the device can spend several seconds recovering from
network instability, and the queue now reflects that work instead of hiding it.

## Phase 6: Active Reading Session

When the user opens an article:

- the reader slice creates or restores a session
- the app runtime renders the reader surface from the reader model
- later paging can trigger additional reader-window loads from storage

Reading remains offline-capable once the package is local.

## Phase 7: Sleep And Long Operations

The current firmware now suppresses inactivity sleep during active fetching so
the device does not deep-sleep in the middle of an uncached package open.

That safeguard now depends on both:

- the fetching state being visible in the collection UI
- the pending prepare staying selected across collection refreshes

This is now part of the real lifecycle for long-running uncached opens.

## Phase 8: Progress And Sync

This area is still incomplete.

The current firmware can open and read backend-provided packages, but it still
does not complete the full remote progress-upload story described in the target
architecture.

## Failure Handling

### No Wi-Fi Or No Backend Path

- cached reading still works
- Saved metadata can remain visible from prior sync
- uncached opens may queue until the backend path becomes usable
- if recovery fails for long enough, the open eventually fails cleanly

### Package Download Failure

- the article remains listed in the queue
- the stage is aborted rather than partially committed
- package state leaves `Fetching` and the user can try again later

### DNS / TLS / Transport Failure

This is now the dominant remaining failure class.

Current package opens can still fail because of:

- DNS failure on device
- TLS handshake timeout
- request flush or body-read instability
- Wi-Fi disconnect/reassociate churn

This is the main reliability frontier now that storage throughput is no longer
the first bottleneck.

### SD Unavailable

- content availability degrades
- internal flash state remains intact
- queue selectors should still reflect that local package access is degraded

## Architectural Consequence

The same boundary rule still holds:

- Wi-Fi owns connectivity evidence
- backend sync owns remote protocol and retry policy
- storage owns staging, commit, and local package opening
- the store coordinates user-visible state
- app/UI consumes selectors and should not reconstruct the pipeline itself

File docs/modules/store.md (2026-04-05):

# Store

## Purpose

The store is the authoritative runtime state container for everything the user
can observe or that multiple modules need to reason about coherently.

It provides:

- one place to derive UI read models from
- one mutation path for domain state
- predictable coordination between app, sync, storage, and connectivity

It does not exist to hold every object in the process.

## Target Slice Layout

The longer-term architecture still targets these slices:

| Slice | Owns |
| --- | --- |
| `device` | pairing identity, firmware-facing device metadata, current time quality |
| `provisioning` | onboarding session state, claim flow status, staged apply status |
| `network` | Wi-Fi status, IP availability, connectivity health |
| `sync` | sync scheduling, in-flight jobs, last-sync state, backoff |
| `content` | source membership, article manifests, local availability, revision state |
| `reader` | active reading session, resume state, speed, completion markers |
| `settings` | user-configurable preferences and persistent app settings |
| `ui` | current screen, focus/navigation context, modal state, screen-local coordination |
| `storage` | storage health, index state, capacity summaries, availability flags |
| `input` | latest delivered gesture, gesture sequence, dropped-gesture diagnostics |
| `sleep` | inactivity timeout, last activity, wake reason, sleep state |
| `power` | placeholder for battery and charging state when hardware exists |

## Current Implemented State

The current `Store` in `crates/domain/src/store.rs` is no longer a tiny
bootstrap shell. It now concretely owns:

- `device`
- `content`
- `input`
- `network`
- `power`
- `reader`
- `settings`
- `sleep`
- `storage`
- `backend_sync`
- `ui`

It also carries one important orchestration helper that is intentionally not a
full slice: a `pending_prepare` request for uncached article opens.

## Current Behavior

Today the store does real cross-module coordination, including:

- recording network-status changes and backend-sync status changes
- queueing an uncached article open when the backend path is not yet usable
- preserving the queued item's `Fetching` state across collection refreshes
- auto-dispatching `PrepareContent(...)` once both network and backend sync are
  in a usable state
- restoring pending prepares if auth becomes invalid
- opening committed reader content and loading later reader windows
- keeping the fetching item selected so the UI reflects the active operation

This means an impatient uncached tap during startup wobble is no longer just
dropped on the floor.

## What The Store Must Not Own

The following still stay outside the store:

- sockets and HTTP clients
- Wi-Fi driver handles
- flash and SD file handles
- framebuffer caches
- renderer glyph caches and layout caches
- parser scratch buffers
- timer objects and scheduler internals

Those belong to services, the platform layer, or the renderer.

## Mutation Model

The current architecture still follows the same write path:

1. a module or platform adapter dispatches a `Command`
2. the store routes the command to the owning slice logic
3. reducers mutate slice state
4. reducers emit zero or more `Effect` values
5. services execute effects
6. services publish typed `Event` values back into the store
7. selectors derive updated read models

That model is now exercising real network/content/storage behavior instead of
only UI and settings.

## Local State Exceptions

These still should not be promoted into the store:

- transport retry internals that do not matter outside backend sync
- parser and formatter scratch buffers
- framebuffer or renderer frame-local bookkeeping
- low-level Wi-Fi driver state

The rule remains: if multiple modules must reason about it, persist it, or
render it, it probably belongs in the store. If it is just service machinery,
it does not.

## Current Missing Pieces

The store is still not the final product model. Important gaps remain:

- provisioning state is not yet first-class
- remote progress upload/reconciliation is not represented end to end
- some long-term content freshness and revision policy remains simplified
- deeper battery/power state is still placeholder-only

But the current store is already a real coordinator for network-aware article
access, not just a UI state bag.

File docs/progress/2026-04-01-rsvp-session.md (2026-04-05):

# Session Progress: RSVP, Theme, And Persistence

This note summarizes the concrete implementation progress completed in the April 1, 2026 session.

Some "still missing" items listed here were addressed in later sessions. See
[Session Progress: Network Reliability And Throughput](2026-04-05-network-reliability-and-throughput.md)
for the newer backend/content pipeline status.

## Implemented

- Replaced the static RSVP placeholder with a real mock-backed reading engine driven from the
  store.
- Added a formatter path that turns built-in script paragraphs into a `ReadingDocument` with:
  - RSVP reading units
  - paragraph anchors
  - stage split data
  - token dwell metadata
- Added contraction-safe token handling so words such as `there's` and `I'd` stay whole.
- Added ORP-style anchor placement and stable stage rendering around a fixed center line.
- Added a dedicated reader tick so RSVP playback advances on time instead of depending on UI
  transition cadence.
- Added live reader progression, pause, paragraph navigation, and resume behavior through the
  store.
- Added active-reader sleep suppression so the device stays awake only during live RSVP playback.
- Tightened the stage split gap so the left and right token segments sit closer together.
- Made the renderer theme-aware and fixed the pause modal to invert against the active theme.

## Settings And Persistence

- Expanded `PersistedSettings` beyond inactivity timeout to also include:
  - reading speed
  - appearance
  - topic preferences
- Added typed `Effect::PersistSettings(...)` so the store requests persistence without writing
  flash directly.
- Wired the platform task to execute that effect through the storage module.
- Preserved backward compatibility with the legacy timeout-only settings payload.
- Confirmed boot hydration still restores settings into the live store and now restores appearance
  as part of the same path.

## Current Product-Level Result

The current firmware now has:

- a usable embedded RSVP reading surface
- timed word progression with punctuation-aware pacing
- pause and paragraph navigation flows
- persisted reader preferences across reboot and deep sleep
- a renderer that follows the persisted light/dark theme

## Still Missing

- backend-supplied article packages flowing through the formatter
- persisted local reading-progress records
- backend progress upload
- final serif typography and final visual tuning
- a dedicated async storage task

## Validation Run

The session changes were validated with:

- `cargo fmt --all`
- `cargo check --offline`
- `cargo clippy --offline --workspace --lib`

Workspace test execution is still constrained by the embedded target and local toolchain setup, so
the repo-level `cargo test --offline --workspace --lib` path remains unavailable in this
environment.

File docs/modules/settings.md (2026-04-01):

# Settings

## Purpose

The settings module owns user-configurable device preferences that must be available as live runtime
state and also survive reboot and deep sleep.

It is separate from `device` state:

- settings are user preferences
- device state is firmware-facing identity and lifecycle state

That means pairing and boot origin do not belong here.

## Current Implementation Boundary

Today the settings path is real across live state, persistence, boot hydration, and rendering.

The current implementation includes:

- a live `settings` slice in the store
- a persisted settings record in internal flash
- bootstrap hydration from flash into the live store
- platform sleep configuration derived from the hydrated settings
- typed `Effect::PersistSettings(...)` emission from the store when persisted preferences change
- platform-side execution of settings writes through the storage module
- one startup log of the effective loaded settings

The current settings schema contains:

- `inactivity_timeout_ms`
- `reading_speed_wpm`
- `appearance`
- `topics`

The default remains `30_000 ms` and light theme when no persisted settings record exists.

## Runtime Ownership

The current source-of-truth split is:

- `Store.settings`
  The live authoritative settings used by the app runtime.
- internal flash persisted settings record
  The durable copy used to restore settings on boot.
- platform storage execution
  The side-effect boundary that applies `PersistSettings` writes emitted by the store.

The live store is the value other modules should observe during runtime.
Flash is a persistence layer, not the live state owner.

## Boot and Deep-Sleep Behavior

Deep sleep is treated as a fresh boot, not as resumed in-memory application state.

On boot, the current runtime:

1. mounts internal storage
2. reads the persisted settings record if one exists
3. builds a `BootstrapSnapshot`
4. constructs `Store::from_bootstrap(...)`
5. configures the platform sleep service from the same hydrated timeout
6. logs the effective `SettingsState`

This guarantees that:

- cold boot and deep-sleep wake use the same hydration path
- the store and platform sleep timeout agree at startup
- the renderer sees the hydrated appearance mode immediately
- defaults are deterministic when no record exists

## Current Field Semantics

### `inactivity_timeout_ms`

This is the inactivity window used by the sleep service before entering deep sleep.

Current behavior:

- stored as milliseconds
- mirrored into `Store.sleep.config.inactivity_timeout_ms`
- applied to the platform sleep service during bootstrap
- defaults to `30_000 ms`

### `reading_speed_wpm`

This is the user's persisted RSVP speed preference.

Current behavior:

- stored as words per minute
- used by the live reader session and pause-speed adjustments
- restored through the same persisted settings snapshot as timeout and appearance

### `appearance`

This is the device-wide light or dark theme.

Current behavior:

- stored as a typed enum
- restored during bootstrap and deep-sleep wake
- propagated through selectors into the renderer
- applied by the renderer as a frame-level theme transform

## Logging

The current firmware logs the effective hydrated settings once during startup.

That log is intended to answer a simple operational question:

- what settings is the device actually running with right now

This log should reflect the live store value, not merely the raw bytes read from flash.

## Future Expansion

This module remains the intended home for future preferences such as:

- font family
- font scale
- future device-level UI behavior

Those should be added as typed fields in the settings model and persisted through the same internal
storage path.

## Non-Goals

The settings module should not own:

- pairing or backend identity
- transport credentials as live runtime state
- flash compaction policy
- sleep hardware entry mechanics

Those belong to `device`, storage, or the platform layer.

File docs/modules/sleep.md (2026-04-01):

# Sleep

## Purpose

The sleep module owns inactivity tracking and deep-sleep entry policy.

It is separate from battery and charging because sleep is required now, while battery telemetry is
not yet wired into the PCB path.

## Current Implementation Boundary

The current implementation uses:

- a singleton-like sleep model that other modules can talk to
- a default inactivity timeout of 30 seconds
- ESP32-S3 deep sleep as the actual sleep mechanism
- `GPIO12` as the provisional wake button input because it is the encoder switch pin and an RTC
  capable GPIO
- a display low-power transition that clears the panel, drives `DISP` and `EMD` low, and holds
  those RTC pins low through deep sleep
- embassy timers in the platform runtime rather than a blocking delay loop

## Intended Behavior

- the device tracks the last activity time
- if no activity occurs for the configured timeout, it enters deep sleep
- wake is expected from a button-style external signal
- the inactivity timeout is currently driven by the hydrated settings model, with a default of
  `30_000 ms` when no settings record exists

More concretely, the current runtime behaves as follows:

- accepted input gestures reset the inactivity timer
- raw button edges do not reset inactivity unless they become a valid delivered gesture
- the wake button is the only deep-sleep wake source
- the wake press is consumed until release so waking does not emit a synthetic click
- app code may request sleep, but the platform layer remains authoritative for actually entering
  deep sleep
- the current timeout can now be hydrated from persisted settings during boot
- active RSVP playback suppresses inactivity sleep while the live reader stage is running
- paused RSVP and paragraph navigation remain eligible for normal inactivity sleep behavior

## Platform Notes

The implementation is built on the `esp-hal` RTC deep-sleep path:

- `Rtc::sleep_deep(&[...])`
- an RTC wake source configured on the wake button pin
- an `EXT0` low-level wake on `GPIO12`
- RTC pull-up enabled on the wake pin before sleep

## Runtime Integration

The current sleep path is split across three layers:

- `domain::sleep`
  platform-agnostic sleep model and timeout tracking
- `services::sleep`
  service boundary for sleep operations
- `platform-esp32s3::sleep`
  real ESP32-S3 deep-sleep entry

The platform runtime computes inactivity deadlines with embassy time and enters deep sleep from the
platform side, not from the store.
The live store mirrors the hydrated timeout and wake state, but deep sleep is still controlled by
the platform sleep service.
The platform deadline logic now also inspects the active prepared screen so only live reader
playback suppresses inactivity sleep.

## Display Interaction

Before deep sleep, the platform layer transitions the display into its lowest current software
state by:

1. clearing the panel
2. driving `DISP` low
3. driving `EMD` low
4. holding those RTC pins low through sleep

The last image may still appear faintly retained on a memory LCD, but that is not the same thing
as active display driving.

## Current Limitations

- the timeout still defaults to `30_000 ms` when no persisted settings record exists
- there is no dedicated wake button yet, so the encoder switch is shared with wake
- wake reason is currently coarse and modeled as external button versus cold boot
- battery telemetry does not participate in sleep policy yet

This keeps the service aligned with the real ESP32-S3 power path rather than a simulated sleep
state.

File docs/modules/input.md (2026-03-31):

# Input

## Purpose

The input module translates physical device interactions into typed gestures the rest of the system
can understand.

It should isolate hardware quirks and debouncing from navigation and reader logic.

## Current Physical Baseline

The current hardware baseline centers on a rotary encoder with a switch input. Future inputs can be
added later without rewriting app logic if the semantic layer stays stable.

## Input Pipeline

The current pipeline is:

1. `PlatformInputService` observes raw pin state
2. the input service debounces and interprets raw signals
3. the input service enqueues typed gestures in its internal fixed-capacity queue
4. the platform runtime loop drains queued gestures
5. the platform runtime publishes `Event::InputGestureReceived(...)` into the app/store path
6. `app_task` updates `Store` and forwards the gesture into `AppRuntime`

The current hardware split is:

- rotary quadrature is polled on a short cadence
- button edges are detected with GPIO interrupts while awake
- the same button remains the deep-sleep wake input

The current runtime constants are:

- rotation poll cadence: `2 ms`
- button debounce: `20 ms`
- long-press threshold: `600 ms`
- gesture queue capacity: `16`
- one rotation gesture per detent threshold of `2` quadrature steps

## Gesture Model

The stable input boundary is gestures, not screen-specific actions.

The current gesture vocabulary is:

- `Rotate { direction: Clockwise }`
- `Rotate { direction: CounterClockwise }`
- `Click`
- `LongPress`

Important behavior defaults:

- one rotation gesture per stable encoder detent
- no acceleration in v1
- long press threshold is `600 ms`
- long press suppresses click
- the wake press is consumed and never replayed as a click
- clockwise and counterclockwise are documented in physical device terms, not screen semantics

## Separation Of Concerns

The input module owns:

- debouncing
- detent interpretation
- press classification
- the transient input queue
- future gesture classification

The input module does not own:

- which screen is active
- which action a given screen treats as confirm or cancel
- reader progression logic

Those belong to the store and app runtime.

## Current Platform Details

The current ESP32-S3 implementation lives in `crates/platform-esp32s3/src/input.rs`.

It uses:

- pull-up inputs on `GPIO10`, `GPIO11`, and `GPIO12`
- a Gray-code transition table for quadrature decoding
- a fixed-size internal queue rather than heap allocation
- button wake suppression until release after deep-sleep boot

Accepted gestures reset inactivity only after they are successfully delivered into the runtime.
Raw GPIO edges do not count as activity on their own.
Dropped gestures are currently logged by the platform layer and are not yet fed back into the
store as a first-class event.

## Focus And Navigation

The app runtime should expose enough focus context that gestures can be interpreted
consistently across screens.

That means:

- queue navigation and settings navigation can interpret the same gestures differently
- the reader surface can reinterpret gestures without redefining raw input behavior
- focus is a UI concern, not an electrical concern

That focus-aware mapping is still future work. Today the runtime stops at gesture delivery and does
not yet translate gestures into queue navigation or reader controls.

## Extension Path

This architecture should support future additions such as:

- multi-click
- wake-from-input semantics
- alternative physical controls

The gesture layer is the compatibility boundary that makes those additions manageable.

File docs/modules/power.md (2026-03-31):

# Power Placeholder

## Status

Battery telemetry and related hardware integration are not currently available on the PCB path, so
this module is a placeholder for architectural completeness rather than an implementation target.

## Why This Module Still Exists In The Design

Power behavior affects product architecture even before the hardware is ready.

Future concerns include:

- battery level visibility
- charging state
- low-power policy that can inform other modules
- background sync limits under low power

If this subsystem is not named early, power behavior tends to leak into unrelated modules later.

## Intended Responsibilities

When the hardware exists, the power module should own:

- battery and charging telemetry
- power-policy decisions
- coordination with the store on device health and availability

## Non-Responsibilities

The power module should not own:

- article sync semantics
- queue derivation
- formatting decisions
- reader UI structure

It may influence those systems through typed events and state, but should not absorb their logic.

## Current Architectural Contract

For now, the architecture should only assume that a future `PowerService` will be able to report:

- battery or power status
- charging status
- fault or degraded-power states

The rest of the system should keep that integration point open without inventing implementation
detail prematurely.

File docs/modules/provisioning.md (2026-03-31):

# Provisioning

## Purpose

Provisioning owns first-time setup and explicit reprovisioning.

Its job is to move Motif from:

- no network
- no backend identity

to:

- one working Wi-Fi network
- one valid backend credential
- a standalone device that no longer depends on the phone

Provisioning is not the normal Wi-Fi runtime and it is not the steady-state backend sync engine.

## Chosen Direction

Motif should use a phone-assisted BLE provisioning flow.

The planned device-side shape is:

- custom BLE onboarding transport
- one provisioning session carrying both Wi-Fi credentials and backend pairing material
- one active remembered Wi-Fi network in v1
- BLE enabled only while the device is unprovisioned or explicitly re-entering provisioning mode
- standalone operation after setup completes

The phone app is a separate project. This repo only defines the device-side architecture and the
contract that app must speak.

## Current Status

Provisioning is intentionally still a skeleton in firmware.

What exists today:

- documentation for the intended BLE-first flow
- shared domain types for provisioning state and bundle shape
- a no-op provisioning service boundary in the services crate

What does not exist yet:

- BLE transport
- QR payload generation or rendering
- Wi-Fi credential exchange
- backend pairing exchange
- commit logic for onboarding records

## Connection Steps

The intended setup flow is:

1. Motif enters provisioning mode when it has no valid network/backend setup, or later when the
   user explicitly asks to reprovision.
2. Motif advertises over BLE and exposes only the onboarding transport.
3. Motif presents a claim payload that lets the phone identify the exact device.
4. The phone app connects over BLE and authenticates the onboarding session.
5. The phone app asks Motif to scan nearby Wi-Fi networks.
6. Motif returns the scan results over BLE.
7. The user picks a network and types the password on the phone.
8. The phone app sends one provisioning bundle containing:
   - selected SSID
   - Wi-Fi password
   - backend pairing token
9. Motif stages that bundle, validates Wi-Fi and backend pairing, and only then commits the new
   live configuration.
10. Motif turns BLE off and continues as a standalone device.

## Reprovisioning Rule

Reprovisioning follows the same flow with one critical rule:

- the last known-good configuration remains active until the replacement has fully succeeded

That prevents a failed reprovision attempt from bricking a working device.

## Module Boundary

Provisioning owns:

- session lifecycle
- claim/auth handshake
- onboarding progress state
- staged apply and commit rules

Provisioning does not own:

- steady-state Wi-Fi reconnect policy
- backend sync scheduling
- article downloads
- general UI navigation

## State Model

The planned provisioning state model is:

- `Disabled`
- `Unprovisioned`
- `Advertising`
- `SessionAuthenticating`
- `ScanningWifi`
- `AwaitingBundle`
- `ApplyingBundle`
- `ConnectingWifi`
- `ValidatingBackend`
- `Provisioned`
- `FailedRetryable`
- `FailedTerminal`

Those states already exist as shared domain vocabulary even though the implementation is still
stubbed.

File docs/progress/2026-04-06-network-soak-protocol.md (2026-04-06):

# Network Soak Protocol

This is the lightweight manual soak loop for comparing firmware runs after the
April 6 reliability tickets.

## Goal

Produce repeatable log captures and comparable reliability summaries without
needing lab automation.

## Capture Command

Use a unique label per run:

```bash
CARGO_TERM_COLOR=never cargo run --release 2>&1 | tee /tmp/motif-<label>.log
```

Generate the report immediately after the session:

```bash
python3 scripts/memtrace_report.py /tmp/motif-<label>.log --out-dir /tmp/motif-<label>-report
```

Primary outputs:

- `summary.md`: human-readable run summary
- `sli.csv`: one-row reliability snapshot for spreadsheet-style comparison
- `request-class-summary.csv`: per-class attempts, success ratio, median, p95
- `log-events.csv`: matched retries, disconnects, fallback, timeout, and SD
  failure lines

## Manual Session Steps

Keep the session short enough to repeat but broad enough to exercise startup,
metadata, cached reads, and uncached package fetch:

1. Boot to the dashboard and wait for `backend status=Ready`.
2. Stay on the dashboard for at least `30s` so background sync has time to
   settle.
3. Open the `Saved` collection and open one cached article.
4. Return to `Saved` and open one uncached article so a package fetch, stage,
   commit, and open happen on the run.
5. In the reader, rotate enough to force at least one additional reader-window
   load.
6. Return to `Saved` and, if available, open one more article whose package
   state differs from the previous one.

If the firmware is specifically under sleep/wake review, add one suspend/resume
cycle after step 4 and note that in the run label.

## Comparison Rules

- Compare runs using `sli.csv` and `request-class-summary.csv`, not by feel.
- Treat `package_success_ratio`, `startup_retry_count`, timeout counts, and SD
  failure counts as the primary reliability gates.
- Treat request-class median and p95 as the primary latency view.
- Do not treat a higher SD clock or other tuning as a win unless the run stays
  clean and the latency summaries improve materially.

## Notes

- `package_success_ratio` is calculated as successful
  `streaming_package` completions divided by `streaming_package` open attempts.
- Request-class latency summaries are derived from successful
  `request_complete` events.
- DNS fallback visibility is expected in `summary.md` and `log-events.csv`
  whenever Ticket 11 is actually exercised on device.

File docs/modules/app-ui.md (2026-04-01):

# App And UI Runtime

## Purpose

The app runtime owns the screens the user experiences. It should feel closer to a component system
than to a collection of full-screen drawing functions.

The target is a modular, composable UI architecture that is expressive enough for motion and
transitions but still disciplined enough for a 1-bit memory LCD.

## Core Surfaces

The first-class app surfaces are:

- `Queue/Library`
  The entry surface for personal saved articles and editorial feed items.
- `Reader`
  The RSVP reading surface.
- `Settings/Sync`
  The place for pairing, connectivity state, sync state, storage health, and device settings.

Article detail or diagnostics can be added later, but should not drive the primary architecture.

## Current Implemented Subset

The current `app-runtime` crate now owns a real first pass of the target architecture.

Today it owns:

- `Screen`
- `NavigationState`
- selector-driven prepared screen composition
- renderer-ready shells for dashboard, collection, reader, paragraph navigation, and settings
- transition planning for list movement, reader entry, modal reveal, settings pulses, and
  paragraph-navigation accents
- gesture mapping from the encoder into typed UI commands

What it does not yet own is a deeper local component state model, region invalidation planning, or
the final production typography system.

## Component Model

The app runtime should be built from components, not from copy-pasted screens.

Each component should have:

- stable identity
- explicit props
- optional local ephemeral state
- layout output
- animation hooks
- children only when composition makes sense

Examples of likely component categories are:

- shells and layout containers
- queue list and queue cards
- reader presentation components
- settings sections and status rows
- badges, tabs, controls, overlays, and sheets

## Render Pipeline

The intended pipeline is:

1. selectors create screen view models from the store
2. components turn those view models into a component tree
3. the runtime resolves layout into a render tree or scene tree
4. the renderer consumes that scene plus invalidation hints
5. the display adapter paints only the work that matters

The renderer should stay an output stage. It should not reconstruct app logic on its own.

## Motion Model

Motion is a first-class design tool in this architecture, but it must be appropriate to the panel.

The right mental model is:

- expressive transitions
- small, bounded geometry changes
- predictable state-driven motion
- no visual tricks that only work on alpha-blended displays

Good motion candidates include:

- slide and anchored repositioning
- card expansion and collapse
- reveal and wipe transitions
- inversion-based emphasis or confirmation pulses
- focus movement that follows the active element

Poor fits for this display include:

- transparency fades
- blur-heavy effects
- long-running continuous decorative motion
- transitions that require repainting large areas without a clear UX payoff

## Animation Ownership

Animations should be described by `AnimationDescriptor` values tied to state transitions.

That means:

- components describe what changed
- the runtime decides what animation applies
- the renderer executes the transition using display-friendly primitives

Animation state should not be hidden in arbitrary widget code or buried inside hardware render
calls.

## Snappy UI Principles

To keep the UI feeling immediate:

- attach motion to user intent and state change, not decoration
- prefer transitions that can begin from already-known layout
- reuse layout and render caches where possible
- avoid full-screen invalidation unless the screen actually changed wholesale
- if a transition would delay real content visibility, prefer showing content first

## What Belongs In The App Runtime

The app runtime owns:

- navigation
- component composition
- focus rules
- screen-local ephemeral state
- animation descriptors
- UI read model consumption

The app runtime does not own:

- content parsing
- network logic
- persistence policy
- Wi-Fi connection machinery
- low-level draw operations

## Reader-Specific Requirements

The reader surface is the most performance-sensitive part of the system. It should:

- consume formatter outputs instead of raw article content
- keep reader controls modular and independently reviewable
- maintain stable layout around the active RSVP presentation region
- isolate speed changes, pauses, and session updates from unrelated UI work

## Queue-Specific Requirements

The queue surface should present personal and editorial sources through one coherent model. It
should not feel like two apps stitched together.

That requires:

- unified card or row primitives
- source-aware but source-agnostic navigation
- consistent availability and sync status indicators
- store-derived sorting and grouping rather than ad hoc service queries

## Settings And Sync Surface

Settings should be treated as a real product surface, not as a debug dump.

It should own:

- pairing state
- Wi-Fi status
- last sync status
- storage health
- reader preferences
- future device and power settings

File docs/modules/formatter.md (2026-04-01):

# Formatter And Content Pipeline

## Purpose

The formatter module is the boundary between raw or normalized content and the structures the reader
can actually present.

It should be open to multiple input sources over time, but it should produce one canonical reading
pipeline.

## Current Implemented Baseline

Today the formatter path is real, but intentionally scoped to the embedded mock corpus.

The current implementation includes:

- a concrete `ReadingDocument` with RSVP units and paragraph anchors
- mock `ArticleDocument` inputs derived from the built-in reader scripts
- apostrophe-aware token handling for common contractions and possessives
- ORP-style anchor metadata and stage split data for the RSVP renderer
- dwell-time metadata derived from token length and punctuation boundaries

What does not exist yet:

- backend normalized article packages flowing through this module
- EPUB or TXT adapters
- persisted formatter caches
- formatter warnings or degradation reporting
- language-specific segmentation beyond the current Latin-script-oriented heuristic

## Primary Input Model

The primary v1 input is a normalized article package from the backend.

That package should be cleaner and more structured than raw HTML, but it should still leave final
reading preparation to the device.

The backend should not send a fully baked RSVP stream as the dominant model.

## Canonical Content Model

The architecture should revolve around a skeleton `ArticleDocument` concept.

At this phase, that concept should include:

- stable identity
- source classification
- revision identity
- article metadata
- structured body content
- optional assets or asset references
- optional reading hints

This is intentionally a skeleton, not a field-complete schema.

## Structured Body Content

The canonical body representation should support article-oriented blocks such as:

- heading
- paragraph
- quote
- list
- code or preformatted block
- divider or callout
- media placeholder where relevant

The key idea is that source-specific parsing happens once, and the rest of the system sees one
shared content model.

## Formatter Output

The formatter should produce a `ReadingDocument` or equivalent structure that contains:

- RSVP-ready reading units
- stable anchors for resume and navigation
- derived reader metadata
- warnings or degradation markers if formatting had to fall back

The reader should consume this output, not reinterpret the original article package.

## Pipeline Stages

The target pipeline is:

1. ingest source package or adapter output
2. normalize text and structural content
3. segment content into reading-oriented units
4. attach anchors and navigation metadata
5. cache or persist formatter output where useful

Each stage should be testable in isolation.

## Source Adapters

The formatter pipeline should support a `SourceAdapter` concept for future imports such as:

- backend normalized article packages
- EPUB
- TXT

These adapters should converge into the same `ArticleDocument` concept before reader formatting.

## Extension Strategy

EPUB and TXT are extension points, not equal primary inputs in the first implementation pass.

That means:

- the canonical content model should be broad enough to support them later
- the module boundaries should anticipate adapters now
- the initial product architecture should still optimize for synced web articles

## Failure Behavior

If formatter preparation fails:

- the article remains part of the local content set
- the queue may still show the item
- the system should report that the content could not be prepared
- failure should not poison unrelated cached content

## Module Boundaries

The formatter owns:

- normalization
- segmentation
- reading-unit generation
- source adapter contracts

The formatter does not own:

- network fetch
- storage placement policy
- reader UI state
- physical rendering

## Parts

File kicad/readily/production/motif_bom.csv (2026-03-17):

Designator | Footprint | Quantity | Value | LCSC Part #
C1 | 0603 | 1 | 4.7uF | C19666
C2 | 0805 | 1 | 22uF | C45783
C3, C5, C9 | 0805 | 3 | 10uF | C15850
C4 | 0603 | 1 | 100nF | C14663
C6 | 0805 | 1 | 47uF | C76636
C7, C8 | 0805 | 2 | 100nF | C49678
D1 | 0603 | 1 | White LED | C2290
D2 | SMF5_0A_C19077497 | 1 | SMF5_0A_C19077497 | C19077497
D3 | 0603 | 1 | LED White | C2290
J3 | TYPE-C16PIN | 1 | USB_C_Receptacle_USB2.0_16P | C393939
MICRO_SD1 | TF-01A | 1 | TF-01A
R1 | 0603 | 1 | 10K | C25804
R10, R9 | 0603 | 2 | 5.1K | C23186
R11, R13, R14, R8 | 0603 | 4 | 10kΩ | C25804
R12 | 0603 | 1 | 2.2K | C4190
R4, R5 | 0603 | 2 | 5.1kΩ | C23186
R6 | 0603 | 1 | 1kΩ | C21190
R7 | 0603 | 1 | 2kΩ | C22975
SW2, SW3 | SW_SPST_B3U-1000P | 2 | SW_SPST | C720477
U1 | ESP32-S3-WROOM-1 | 1 | ESP32-S3-WROOM-1
U2 | Texas_DSQ0010A_WSON-10-1EP_2x2mm_P0.4mm_EP0.9x1.5mm | 1 | BQ24040DSQR | C81080
U3 | Texas_DRT-3 | 1 | TPD2EUSB30
U4 | WSON-6-1EP_2x2mm_P0.65mm_EP1x1.6mm | 1 | TLV75533PDRV
U5 | WAFER-PH2_0-2PWZ | 1 | WAFER-PH2_0-2PWZ | C5359610
U7 | ED08907M-FB15C7_0-C10-2049 | 1 | ED08907M-FB15C7_0-C10-2049 | C18213496

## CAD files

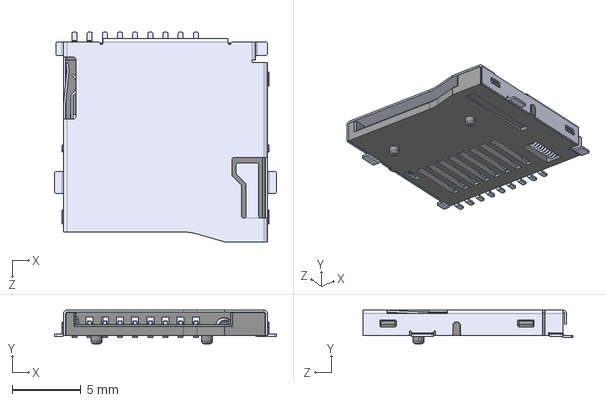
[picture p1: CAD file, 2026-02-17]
kicad/readily/modules/TF-01A/TF-01A.step
16.1 x 2.45 x 15.2 mm

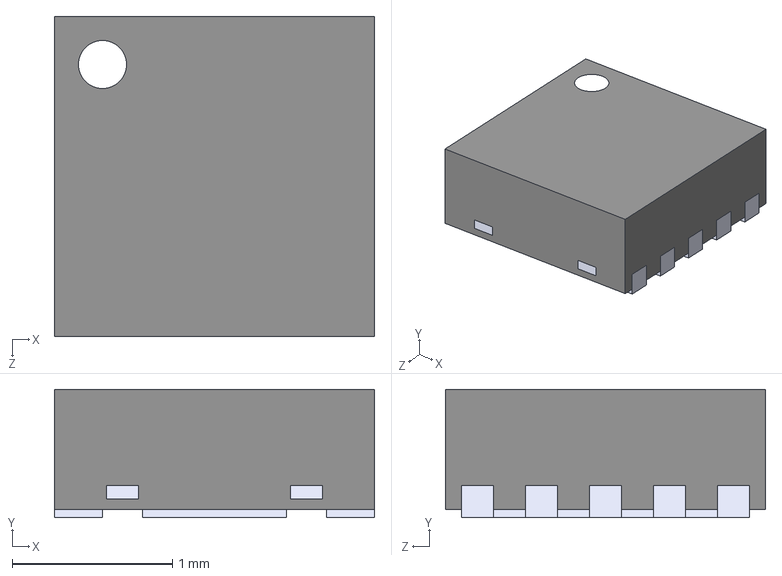
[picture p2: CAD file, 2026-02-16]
kicad/readily/modules/BQ24040DSQR/BQ24040DSQR.step
2.00 x 0.8 x 2.00 mm

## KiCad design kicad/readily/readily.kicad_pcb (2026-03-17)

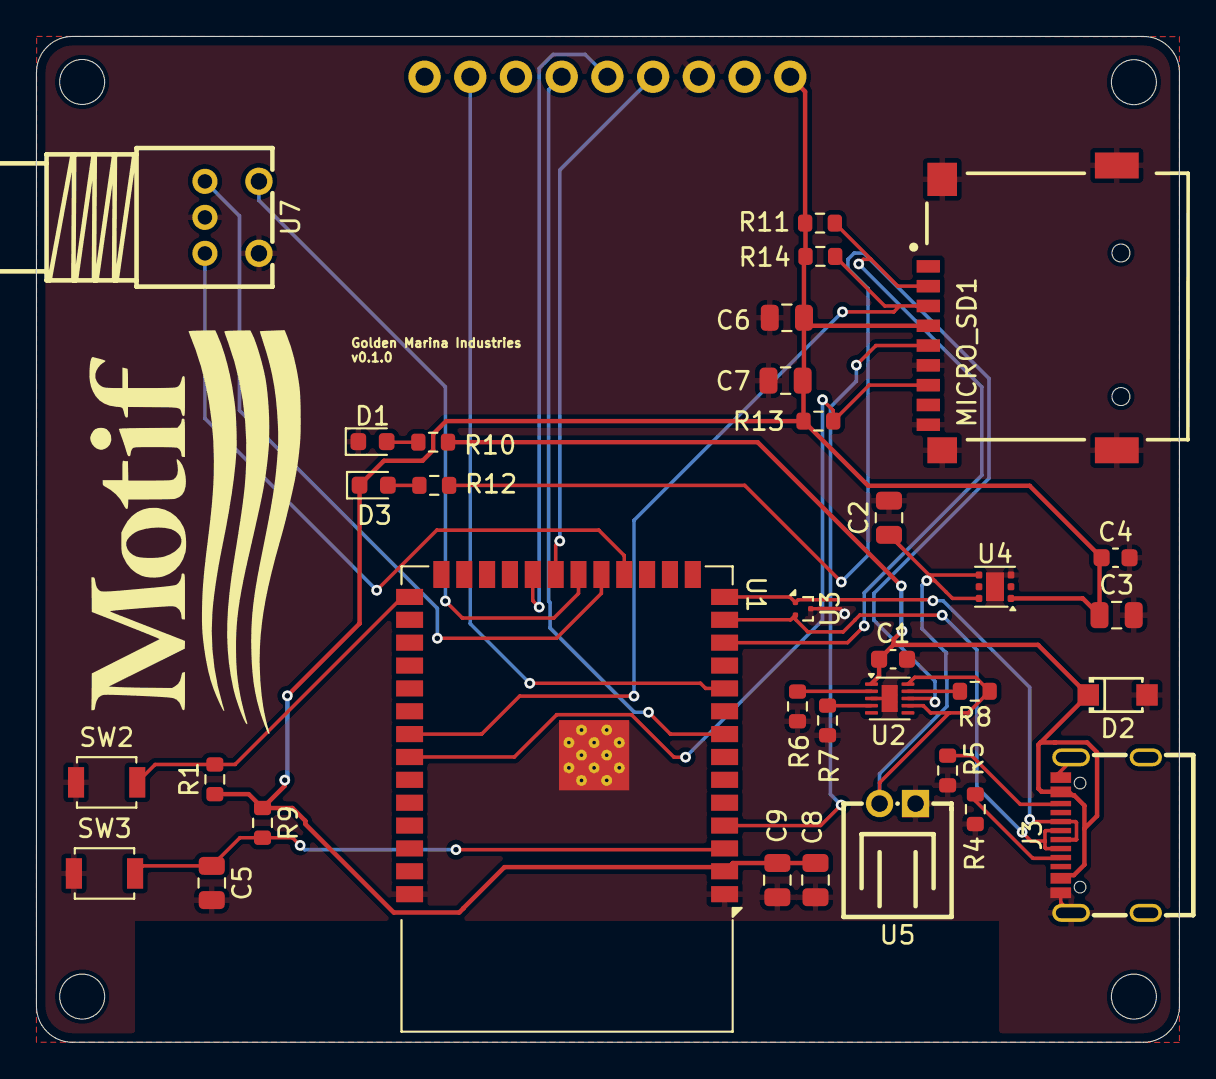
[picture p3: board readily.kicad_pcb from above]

Board: 2 copper layers, 63.5 x 55.9 mm, 39 parts (0 on the bottom side), 27 nets.

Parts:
C1: 4.7uF; C_0603_1608Metric
C2: 22uF; C_0805_2012Metric
C3, C5, C9: 10uF; C_0805_2012Metric
C4: 100nF; C_0603_1608Metric
C6: 47uF; C_0805_2012Metric
C7, C8: 100nF; C_0805_2012Metric
D1: White LED; LED_0603_1608Metric
D2: SMF5_0A_C19077497
D3: LED White; LED_0603_1608Metric
J1: Conn_01x09_Socket; Pins01x09
J3: USB_C_Receptacle_USB2.0_16P; TYPE-C16PIN
MICRO_SD1: TF-01A
Mount1, Mount2, Mount3, Mount4: MountingHole_2.5mm
R1: 10K; R_0603_1608Metric
R4, R5: 5.1kΩ; R_0603_1608Metric
R6: 1kΩ; R_0603_1608Metric
R7: 2kΩ; R_0603_1608Metric
R8, R11, R13, R14: 10kΩ; R_0603_1608Metric
R9, R10: 5.1K; R_0603_1608Metric
R12: 2.2K; R_0603_1608Metric
SW2, SW3: SW_SPST; SW_SPST_B3U-1000P
U1: ESP32-S3-WROOM-1
U2: BQ24040DSQR; Texas_DSQ0010A_WSON-10-1EP_2x2mm_P0.4mm_EP0.9x1.5mm
U3: TPD2EUSB30; Texas_DRT-3
U4: TLV75533PDRV; WSON-6-1EP_2x2mm_P0.65mm_EP1x1.6mm
U5: WAFER-PH2_0-2PWZ
U7: ED08907M-FB15C7_0-C10-2049

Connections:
+3V3: C3.1, C4.1, C6.2, C7.2, C8.1, C9.1, D3.1 (K), J1.1, MICRO_SD1.4 (VDD), R1.1, R9.1, R11.2, R13.2, R14.2, U1.2 (3V3), U4.1 (OUT)
+5V: C1.1, D2.1 (K), J3.+5V, R10.1, U2.1 (IN)
BAT_CHG: R12.1, U2.8 (~CHG)
D+: J3.A6 (D+), J3.B6 (D+), U1.14 (USB_D+), U3.1 (D+)
D-: J3.A7 (D-), J3.B7 (D-), U1.13 (USB_D-), U3.2 (D-)
DISP_CLK: J1.4, U1.21 (IO13)
DISP_CS: J1.6, U1.8 (IO15)
DISP_DI: J1.5, U1.22 (IO14)
DISP_DISP: J1.8, U1.10 (IO17)
EN: C5.1, R9.2, SW3.2 (B), U1.3 (EN)
GND: C1.2, C2.2, C3.2, C4.2, C5.2, C6.1, C7.1, C8.2, C9.2, D1.1 (K), D2.2 (A), J1.3, J3.1, J3.2, J3.GND, MICRO_SD1.6 (VSS), MICRO_SD1.CD1 (CD), MICRO_SD1.MP1 (SHIELD), MICRO_SD1.MP2 (SHIELD), MICRO_SD1.MP3 (SHIELD), MICRO_SD1.MP4 (SHIELD), R4.1, R5.2, R6.1, R7.1, SW2.1 (A), SW3.1 (A), U1.1 (GND), U1.40 (GND), U1.41 (GND), U2.3 (VSS), U2.11 (EXP), U3.3 (GND), U4.3 (GND), U4.7 (GND), U5.1, U7.C, U7.S2
GPIO0: R1.2, SW2.2 (B), U1.27 (IO0)
unnamed: D1.2 (A), R10.2
unnamed: D3.2 (A), R12.2
unnamed: J3.A5 (CC1), R4.2
unnamed: J3.B5 (CC2), R5.1
unnamed: R6.2, U2.2 (ISET)
unnamed: R7.2, U2.4 (PRETERM)
unnamed: R8.2, U2.9 (TS)
RT_CLK: U1.18 (IO10), U7.A
RT_DT: U1.19 (IO11), U7.B
RT_SW: U1.20 (IO12), U7.S1
SD_CLK: MICRO_SD1.5 (CLK), U1.4 (IO4)
SD_CS: MICRO_SD1.2 (CD/DAT3), R11.1, U1.12 (IO8)
SD_MISO: MICRO_SD1.7 (DAT0), R13.1, U1.34 (IO41)
SD_MOSI: MICRO_SD1.3 (CMD), R14.1, U1.33 (IO40)
SYS_OUT: C2.1, R8.1, U2.7 (ISET2), U2.10 (OUT), U4.4 (EN), U4.6 (IN), U5.2

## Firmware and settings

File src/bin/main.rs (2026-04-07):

#![no_std]
#![no_main]
#![deny(
    clippy::mem_forget,
    reason = "mem::forget is generally not safe to do with esp_hal types, especially those \
    holding buffers for the duration of a data transfer."
)]
#![deny(clippy::large_stack_frames)]

#[panic_handler]
fn panic(info: &core::panic::PanicInfo) -> ! {
    esp_println::println!("panic: {}", info);
    loop {
        core::hint::spin_loop();
    }
}

esp_bootloader_esp_idf::esp_app_desc!();

#[cfg(feature = "firmware-info-logs")]
const FIRMWARE_LOG_LEVEL: log::LevelFilter = log::LevelFilter::Info;
#[cfg(not(feature = "firmware-info-logs"))]
const FIRMWARE_LOG_LEVEL: log::LevelFilter = log::LevelFilter::Warn;

#[esp_rtos::main]
async fn main(spawner: embassy_executor::Spawner) -> ! {
    esp_println::logger::init_logger(FIRMWARE_LOG_LEVEL);
    esp_println::println!("boot: motif minimal firmware");
    platform_esp32s3::bootstrap::run_minimal(spawner).await
}

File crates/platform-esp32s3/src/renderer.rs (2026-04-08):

use core::{convert::Infallible, fmt::Write};

use app_runtime::{
    AnimationDescriptor, MotionDirection, PreparedScreen, Screen, ScreenUpdate, TransitionPlan,
    components::{
        ContentListShell, ContentRow, DashboardShell, LoadingModal, ParagraphNavigationShell,
        PauseModal, ReaderModal, ReaderShell, RecommendationBar, SettingsShell, StartupSplashShell,
        TopicPreferenceGrid,
    },
};
use domain::formatter::StageFont;
use domain::settings::AppearanceMode;
use domain::ui::TopicRegion;
use embedded_graphics::{
    mono_font::{
        MonoFont, MonoTextStyleBuilder,
        iso_8859_1::{FONT_6X10, FONT_8X13, FONT_8X13_BOLD, FONT_10X20},
    },
    pixelcolor::BinaryColor,
    prelude::*,
    text::{Alignment, Baseline, Text, TextStyleBuilder},
};
use heapless::String as HeaplessString;
use ls027b7dh01::FrameBuffer;

pub const UI_TICK_MS: u64 = 160;
const NORMALIZED_TEXT_MAX_BYTES: usize = 192;
const ELLIPSIS: &str = "...";
const RSVP_STAGE_CENTER_X: i32 = 170;
const RSVP_STAGE_LEFT_ANCHOR_X: i32 = 169;
const RSVP_STAGE_RIGHT_ANCHOR_X: i32 = 173;
const RSVP_STAGE_SCALED_LEFT_ANCHOR_X: i32 = 168;
const RSVP_STAGE_SCALED_RIGHT_ANCHOR_X: i32 = 172;
const LIST_REGION_X: i32 = 16;
const LIST_REGION_WIDTH: i32 = 368;
const DASHBOARD_TEXT_RIGHT_EDGE_X: i32 = 380;
const DASHBOARD_SLOT_TRAVEL_PX: i32 = 18;
const DASHBOARD_SLOT_SWAY_PX: i32 = 10;
const DASHBOARD_BAND_RIGHT_SLOPE_PX: i32 = 18;
const DASHBOARD_TOP_SLOT_Y: i32 = 42;
const DASHBOARD_TOP_SLOT_HEIGHT: i32 = 40;
const DASHBOARD_SELECTED_SLOT_Y: i32 = 82;
const DASHBOARD_SELECTED_SLOT_HEIGHT: i32 = 60;
const DASHBOARD_BOTTOM_SLOT_Y: i32 = 149;
const DASHBOARD_BOTTOM_SLOT_HEIGHT: i32 = 42;
const COLLECTION_TEXT_RIGHT_EDGE_X: i32 = 368;
const COLLECTION_LIST_STEP_TRAVEL_PX: i32 = 18;
const COLLECTION_SLOT_SWAY_PX: i32 = 6;
const COLLECTION_BAND_RIGHT_SLOPE_PX: i32 = 12;
const COLLECTION_TOP_SLOT_Y: i32 = 42;
const COLLECTION_TOP_SLOT_HEIGHT: i32 = 42;
const COLLECTION_SELECTED_SLOT_Y: i32 = 106;
const COLLECTION_SELECTED_SLOT_HEIGHT: i32 = 68;
const COLLECTION_BOTTOM_SLOT_Y: i32 = 179;
const COLLECTION_BOTTOM_SLOT_HEIGHT: i32 = 42;
const RECOMMENDATION_COLLECTION_TOP_SLOT_Y: i32 = 56;
const RECOMMENDATION_COLLECTION_TOP_SLOT_HEIGHT: i32 = 42;
const RECOMMENDATION_COLLECTION_SELECTED_SLOT_Y: i32 = 100;
const RECOMMENDATION_COLLECTION_SELECTED_SLOT_HEIGHT: i32 = 64;
const RECOMMENDATION_COLLECTION_BOTTOM_SLOT_Y: i32 = 167;
const RECOMMENDATION_COLLECTION_BOTTOM_SLOT_HEIGHT: i32 = 42;
const COLLECTION_BADGE_RIGHT_EDGE_X: i32 = 380;
const COLLECTION_SELECTED_BADGE_RIGHT_EDGE_X: i32 = 372;
const COLLECTION_BADGE_GAP_PX: i32 = 8;
const COLLECTION_BADGE_MIN_WIDTH: i32 = 22;
const COLLECTION_BADGE_HEIGHT: i32 = 15;
const COLLECTION_BADGE_TEXT_Y_OFFSET: i32 = 2;
const RECOMMENDATION_BAR_LEFT_BUTTON_X: i32 = 18;
const RECOMMENDATION_BAR_RIGHT_BUTTON_X: i32 = 356;
const RECOMMENDATION_BAR_BUTTON_Y: i32 = 28;
const RECOMMENDATION_BAR_BUTTON_WIDTH: i32 = 20;
const RECOMMENDATION_BAR_BUTTON_HEIGHT: i32 = 22;
const RECOMMENDATION_BAR_X: i32 = 44;
const RECOMMENDATION_BAR_Y: i32 = 27;
const RECOMMENDATION_BAR_HEIGHT: i32 = 24;
const RECOMMENDATION_BAR_GAP_X: i32 = 6;
const RECOMMENDATION_BAR_RIGHT_EDGE_X: i32 = 350;
const RECOMMENDATION_BAR_TEXT_Y_OFFSET: i32 = 7;
const RECOMMENDATION_BAR_MIN_WIDTH: i32 = 64;
const PARAGRAPH_SLOT_TRAVEL_PX: i32 = 18;
const PARAGRAPH_TOP_SLOT_Y: i32 = 52;
const PARAGRAPH_TOP_SLOT_HEIGHT: i32 = 24;
const PARAGRAPH_SELECTED_SLOT_Y: i32 = 88;
const PARAGRAPH_SELECTED_SLOT_HEIGHT: i32 = 82;
const PARAGRAPH_BOTTOM_SLOT_Y: i32 = 184;
const PARAGRAPH_BOTTOM_SLOT_HEIGHT: i32 = 44;
const PARAGRAPH_CARD_X: i32 = 20;
const PARAGRAPH_CARD_Y: i32 = 88;
const PARAGRAPH_CARD_WIDTH: i32 = 304;
const PARAGRAPH_CARD_HEIGHT: i32 = 82;
const PARAGRAPH_CARD_LABEL_Y: i32 = 106;
const PARAGRAPH_CARD_EXCERPT_Y: i32 = 126;
const PARAGRAPH_CARD_HINT_X: i32 = 236;
const PARAGRAPH_CARD_HINT_Y: i32 = 146;
const PARAGRAPH_CARD_HINT_WIDTH: i32 = 72;
const PARAGRAPH_CARD_HINT_HEIGHT: i32 = 16;
const PARAGRAPH_FOOTER_Y: i32 = 231;
const PAUSE_MODAL_CENTER_X: i32 = 200;
const PAUSE_MODAL_CENTER_Y: i32 = 118;
const PAUSE_MODAL_MIN_WIDTH: u32 = 112;
const PAUSE_MODAL_MIN_HEIGHT: u32 = 52;
const PAUSE_MODAL_MAX_WIDTH: u32 = 286;
const PAUSE_MODAL_MAX_HEIGHT: u32 = 188;
const PAUSE_MODAL_CONTENT_OFFSET_PX: i32 = 8;
const READER_TEXT_LEFT_X: i32 = 20;
const READER_TEXT_RIGHT_X: i32 = 380;
const READER_TITLE_MAX_WIDTH_PX: i32 = READER_TEXT_RIGHT_X - READER_TEXT_LEFT_X;
const READER_FOOTER_WPM_GAP_PX: i32 = 16;
const READER_PREVIEW_Y: i32 = 214;
const STARTUP_WORDMARK_X: i32 = 44;
const STARTUP_WORDMARK_Y: i32 = 54;
const STARTUP_WORDMARK_HEIGHT: i32 = 88;
const STARTUP_WORDMARK_GAP_X: i32 = 8;
const STARTUP_WORDMARK_STROKE_RADIUS: i32 = 13;
const STARTUP_LOADING_BAR_X: i32 = 82;
const STARTUP_LOADING_BAR_Y: i32 = 168;
const STARTUP_LOADING_BAR_WIDTH: i32 = 244;
const STARTUP_LOADING_BAR_HEIGHT: i32 = 16;
const STARTUP_SKIP_HINT_Y: i32 = 205;

#[derive(Debug, Clone, Copy, PartialEq)]
struct StageTextSpec {
    font: &'static MonoFont<'static>,
    y: i32,
    scale: u32,
    left_anchor_x: i32,
    right_anchor_x: i32,
}

#[derive(Debug, Clone, Copy, Eq, PartialEq)]
struct ClipRect {
    x: i32,
    y: i32,
    width: i32,
    height: i32,
}

#[derive(Debug, Clone, Copy, Eq, PartialEq)]
struct CollectionRowSlot {
    text_x: i32,
    meta_y: i32,
    title_y: i32,
    color: BinaryColor,
    clip: ClipRect,
}

#[derive(Debug, Clone, Copy, Eq, PartialEq)]
struct RowTransitionOffsets {
    incoming_x: i32,
    outgoing_x: i32,
    incoming_y: i32,
    outgoing_y: i32,
}

#[derive(Debug, Clone, Copy, Eq, PartialEq)]
struct ClippedTextSpec {
    position: Point,
    color: BinaryColor,
    alignment: Alignment,
    max_width_px: i32,
}

#[derive(Debug, Clone, Copy)]
struct TextPairSlotSpec {
    slot: CollectionRowSlot,
    font: &'static MonoFont<'static>,
    max_width_px: i32,
}

fn ui_font_small() -> &'static MonoFont<'static> {
    &FONT_6X10
}

fn ui_font_body() -> &'static MonoFont<'static> {
    &FONT_8X13
}

fn ui_font_title() -> &'static MonoFont<'static> {
    &FONT_10X20
}

fn stage_font_spec(font: StageFont) -> StageTextSpec {
    match font {
        StageFont::Large => StageTextSpec {
            font: ui_font_title(),
            y: 102,
            scale: 2,
            left_anchor_x: RSVP_STAGE_SCALED_LEFT_ANCHOR_X,
            right_anchor_x: RSVP_STAGE_SCALED_RIGHT_ANCHOR_X,
        },
        StageFont::Medium => StageTextSpec {
            font: &FONT_8X13_BOLD,
            y: 108,
            scale: 2,
            left_anchor_x: RSVP_STAGE_SCALED_LEFT_ANCHOR_X,
            right_anchor_x: RSVP_STAGE_SCALED_RIGHT_ANCHOR_X,
        },
        StageFont::Small => StageTextSpec {
            font: ui_font_title(),
            y: 112,
            scale: 1,
            left_anchor_x: RSVP_STAGE_LEFT_ANCHOR_X,
            right_anchor_x: RSVP_STAGE_RIGHT_ANCHOR_X,
        },
    }
}
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

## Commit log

2026-02-13 feat: adding sleep for the esp32
2026-02-13 fix: trying to fix the loading of chapters after a refresh
    [input.rs, main.rs]
2026-02-16 feat: adding the kicad design
    [BQ24040DSQR.step, readily.kicad_pcb, readily.kicad_sch]
2026-02-17 feat: adding the first stage of the PCB
    [TF-01A--3DModel-STEP-56544.STEP, TF-01A.step, readily.kicad_pcb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]
2026-02-17 fix: cleared out all DRC errors
    [readily.kicad_pcb]
2026-02-17 feat: adding vias and tracks to all components
    [readily.kicad_pcb]
2026-02-19 feat: updating the specs with the final rotatory encoder switch
    [readily.kicad_pcb, readily.kicad_sch]
2026-02-19 feat: version 1.0 of the pcb
    [readily.kicad_pcb, readily.kicad_sch]
2026-02-19 feat: adding the metadata
    [readily.kicad_pcb]
2026-03-11 feat: updating the screen position
    [readily.kicad_pcb]
2026-03-16 feat: adding logo to pcb, improving component placement and changing the battery connector to two pin JST
    [readily.kicad_pcb, readily.kicad_sch]
2026-03-16 feat: adding a GND plane to achieve higher power stability and heat management
    [readily.kicad_pcb]
2026-03-16 feat: finishing the power refactor on the board
    [readily.kicad_pcb, readily.kicad_sch]
2026-03-17 feat: updating and rerouting all components
    [readily.kicad_pcb, readily.kicad_sch]
2026-03-17 feat: switching the battery JST and generating the final files for next print
    [motif_bom.csv, motif_designators.csv, motif_positions.csv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]
2026-03-31 feat: initial basics of the architecture
    [motif.csv]
2026-03-31 feat: latest changes on the kicad schematics
2026-04-03 feat: adding wifi and backend support to the device
2026-04-04 feat: improving stability from article to article by poping out the cache
    [bootstrap.rs, content_storage.rs, input.rs]
2026-04-06 feat: switching the input on the RSVP view
2026-04-06 feat: spi robustness
2026-04-07 Tune article transfers and restore failed fetch retries
    [bootstrap.rs, content_storage.rs, main.rs]
